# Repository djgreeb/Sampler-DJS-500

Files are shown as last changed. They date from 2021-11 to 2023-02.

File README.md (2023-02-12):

# Sampler DJS-500 nexus

This is a sampler project that has a design in CDJ-2000 nexus and DJM-900 nexus style. The look and feel and the GUI have the same style. 
Sampler based on STM32F746G-DISCO board and pads from Akai LPD8. Replaced RGB LEDs in the pads.
The sampler supports Pro Dj Link. It automatically selects the master deck, can receive information about BPM and beat moments, beats from the CDJ. 
This allows you to synchronize samples with the track on the air, as well as trigger samples without delays using quantize.
Samples are stored on a micro SD card, wav format is supported.

https://youtu.be/_pMT7O0JRTI

https://youtu.be/_ofyAOzehKc

https://youtu.be/i8zc_d4uLBs

https://youtu.be/rUySWEsYK1w

# The current firmware version is 1.77

	ver. 0.35
		- added all periph buttons, leds, VRs and encoder
	ver. 0.36
		- added buttons handler
	ver. 0.37
		- added USB USART debug code
		- added first service mode 
	ver. 0.38
		- improved encoder noise canceller code
	ver. 0.41
		- added service mode code parts
		- added ADCs VRs code with hysteresis and filter
	ver. 0.45
		- added service mode code parts
	ver. 0.46
		- fixed SERVICE MODE code
	ver. 0.47
		- added sync out led blink
	ver. 0.48
		- the signals from the pads are inverted, the pullups are replaced with pulldowns. It is also changed in the hardware
	ver. 0.49
		- added PWM backlight
	ver. 0.51
		- added PRESETS select display
	ver. 0.53
		- added reading preset preview pads color, rating
		- added loading presets from preset list
		- added long blink encoder led if the preset is loaded for a very long time 
	ver. 0.54
		- added color instruments icons
		- added shadow at the rating stars
	ver. 0.57
		- added sync pitch 
		- added imitate deck mode
		- added blink pads
	ver. 0.61
		- added dynamic timeline on waveforms 
		- added colored CUE points and colored samle name
	ver. 0.63
		- added first sequencer
	ver. 0.65
		- minor fixes for the GUI sequencer
		- added status bar with playback status
		- added icons for effect and sync. out
	ver. 0.67
		- added on-off pads label
	ver. 0.68
		- minor fixes GUI
	ver. 0.70
		- fixed pad1 RGB led problem
		- minor fixes
	ver. 0.72
		- minor GUI fixes
		- added UTILITY window
		- added master bpm shield
	ver. 0.73
		- added timestamp for pads press moments and filter 
		- added ATT_LV for pads
	ver. 0.74
		- changed "+" symbol in 15P font
		- minol fixes in gui preset list
		- added gui.h and audio.h
	ver. 0.77
		- added EDIT PRESER window
		- changed SYNC OUT and EFFECT GUI gray color
	ver. 0.79
		- improved debug mode
		- added interrupt for received uart
	ver. 0.80
		- added processing to the EDIT for the encoder button
		- changed project structure main.c file is split into many * .h files
	ver. 0.81
		- added preset list edit menu
	ver. 0.87
		- added DELETE DIALOG
		- added encoder_handler.h, key_handler.h
		- improved  DELETE DIALOG
		- added noise filter for encoder button
	ver. 0.88
		- fixed fixed bugs in GUI UTILITY
		- improved GUI preset list
		- improved the mechanism for creating screenshots, using both layers
	ver. 0.89
		- improved configuration in ffconf.h
	ver. 0.90
		- improved preset list gui
	ver. 0.91
		- improved UTILITY
		- add edit pad display, edit preset display, edit FL display
	ver. 0.94
		- improved UTILITY id address set
	ver. 0.98
		- added utility edit menu
		- added internal bpm generator
	ver. 1.06
		- added write uSD prc
	ver. 1.09
		- added edit preset display
		- added write preset uSD prc 
		- added keyboard and rename prc		
		- added keyboard animation	
	ver. 1.17
		- added blinking cursor for kyeboard
		- added waveform editor
		- improved edit pad display gui
		- improved home display gui
		- added simple waveform analyzer
	ver. 1.19
		- improved edit pad display
		- added prompt for edit pad display
		- added prompt for edit preset display
		- added first BROWSER display
	ver. 1.23
		- replaced FATFS lib! (previous lib not work USE_LFN for READDIR)
	ver. 1.25
		- fixed display of sample names inside folders. Folder removed from title bar
		- fixed edit pad GUI bugs
		- added realtime pad color update when editing a pad
	ver. 1.26
		- fixed ethernetif.c beat process for external sync
		- added FLLIST_DISPLAY
	ver. 1.28
		- added sequence editor
	ver. 1.31
		- minor fixes
		- added [folder] style in BROWSER display
		- added dynamic pad in edit pad display gui
	ver. 1.33
		- added first FL presets animation
	ver. 1.34
		- improved FL presets animation
	ver. 1.35
		- added "create new preset" and "create duplicate" process
	ver. 1.36
		- improved "create new preset" and "create duplicate" process
		- added "preset list is full" and "error x" msg
		- added automaticly wzoom for waveform
	ver. 1.37
		- added noise filters for buttons PRESET, SHIFT, EDIT, BACK, EFFECT
	ver. 1.39
		- added delete prc
		- fixed display of MAC-address in service mode
	ver. 1.40
		- fixed delete prc
	ver. 1.42
		- work on the edit fl list
	ver. 1.43
		- new FL preset load animation
	ver. 1.44
		- added background picture on edit preset display
		- added FIR filter in WFMCREATE()
	ver. 1.47
		- improved WFMCREATE(), FIR and analising algorythm
		- the algorithm for displaying a big waveform has been changed
		- added a mechanism for creating a template Presets.pst file on an empty sd card
	ver. 1.48
		- changed color map for big waveform
	ver. 1.51
		- fixed a bug: where inactive pads in the edit_pad_display would start glowing after the pad_x being edited was stopped
		- improved edit_pad_display
	ver. 1.55
		- bug fixes in the function REDRAW_PAD_EDIT()
		- added first move preset display
	ver. 1.56
		- bug fixes in the MOVE_PRESET	
		- first move_preser_prc
	ver. 1.57
		- improved move_preser_prc	
	ver. 1.59
		- bug fixes in the function REDRAW_PAD_EDIT()
		- added new icons for presets
	ver. 1.60
		- added new icons for presets
	ver. 1.61
		- changed PLL frequency multiplier PeriphClkInitStruct.PLLI2S.PLLI2SN = 271 (135 old)
	ver. 1.65
		- quantize first
	ver. 1.68
		- improved quantize process
		- minor fixes
		- added first effects
	ver. 1.69
		- improved trans effect process
	ver. 1.70
		- optimized and improved trans effect process
	ver. 1.71
		- added ram fill percentage status
	ver. 1.73
		- optimized HAL_SAI_Transmit_IT
		- added uart sync out signal
	ver. 1.74
		- bug fixed in audio handler limiting play_adr size at 0xFFFFF
		- added errors descriptor
		- bug fixed in waveform color draw_st_wvfm()
	ver. 1.75
		- changed the principle of operation of SPI2 for PADS LEDs. Now SPI2 works via DMA.
	ver. 1.77
		- improved performance of Moog Filter and LPF

# Menu navigation
Menu navigation

# Screenshots
SCREEN_009
SCREEN_110
SCREEN_124
SCREEN_176
SCREEN_189
SCREEN_191
SCREEN_195
SCREEN_217 new
SCREEN_217
SCREEN_236
SCREEN_249
SCREEN_285
SCREEN_414
SCREEN_449_new
SCREEN_456
SCREEN_475
SCREEN_734
SCREEN_740
SCREEN_749
SCREEN_757
SCREEN_758
SCREEN_795
SCREEN_839
SCREEN_905_new
SCREEN_956

Some photos:

2020_07_29_23_54_IMG_2746
2020_08_02_23_38_IMG_2779
2020_09_19_19_30_IMG_2952
2020_09_19_19_30_IMG_2953
2020_09_29_15_57_IMG_3006
2020_09_30_11_38_IMG_3007
2020_10_15_12_30_IMG_3105
2020_11_01_00_35_IMG_3214
2020_11_01_02_20_IMG_3215
2020_11_01_15_38_IMG_3219
2020_11_01_21_26_IMG_3228
2020_11_01_21_26_IMG_3229
2020_11_03_14_13_IMG_3241
2020_11_03_21_55_IMG_3242
2020_11_03_23_34_IMG_3244
2020_11_23_22_04_IMG_3343
2020_11_29_21_47_IMG_3356
2020_11_29_21_54_IMG_3357
2020_12_03_11_01_IMG_3373
2020_12_04_14_35_IMG_3376
2020_12_04_21_59_IMG_3377
2020_12_05_16_33_IMG_3378
2020_12_05_17_58_IMG_3380
2020_12_05_17_58_IMG_3381
2020_12_15_12_30_IMG_3422
2020_12_15_12_30_IMG_3423
2020_12_15_12_30_IMG_3424
2020_12_15_12_31_IMG_3425
2020_12_17_21_16_IMG_3439

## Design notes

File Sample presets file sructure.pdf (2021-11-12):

## Sample presets file structure

10.03.2021

## Pad structure [192]:

| 0 | 1 | 2 | 3 | 4 | 5 | 6 | 7 | 8 | 9 | 10 | 11 | 12 | 13 | 14 | 15
0 | ENB | COL | TYPE | Q | S | TRIG | BPM | | G | ST | ST | ST | AL | AL | AL | AL
16 | Sample name. Max 64 symbols.
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
Waveform data [100] or sequencer[64] + number of squares[1]

176 | 0 | 0 | 0 | 0 | 0 | 0 | 0 | 0 | 0 | 0 | 0 | 0

ENB – enable pad. 0 – none, 135 – enable.

COL – color pad. 0 – pink, 1 – red, 2 – orange, 3 – yellow, 4 – green, 5 – aqua, 6 – blue, 7 – purple. 0xFF – none.

TYPE – type pad. 0 – sample, 1 – sequencer.

Q – quantize. 0 – none, 1 – enable.

S – sync only BPM sample to master track.

TRIG – trigger. 0 – one shot, 1 – loop.

BPM – original sample’s BPM. (BPM*10).

G – GAIN in –dB. (-dB*10).

ST – start position in audio frames (3 bytes).

AL - total long track in audio frames (4 bytes). (IS NOT LONG DATA IN FILE. IT IS DATA IN SDRAM)

Waveform data: MSB bit – color, 4 LSB bits – amplitude.

Sequencer: byte==0 – none, byte==1 – start sample. Number of squares byte==0 (1 square). byte==3 (4 square (max)).

## Preset structure [1584]:

Max. 64 presets.

| 0 | 1 | 2 | 3 | 4 | 5 | 6 | 7 | 8 | 9 | 10 | 11 | 12 | 13 | 14 | 15
0 | ENB | ICON | RAT | RCOL | 0 | 0 | 0 | 0 | 0 | 0 | 0 | 0 | 0 | 0 | 0 | 0
16 | Preset name. Max 32 symbols.
32
48
PAD 0[192]

224
240 | PAD 1[192]

416
432

608

PAD 2[192]

624

800

PAD 3[192]

816

992

PAD 4[192]

1008

1184

PAD 5[192]

1200

1376

PAD 6[192]

1392

1568

PAD 7[192]

ENB – enable preset. ENB==117 – preset enable.

ICON – type preset icon

RAT – rating 0…5

RCOL – rating color 0…7 and 0xFF - default

Path: 0:/SAMPLER/ Presets.pst

File name: Presets.pst

## Sample presets file structure[48+TPRS*1584]

| 0 | 1 | 2 | 3 | 4 | 5 | 6 | 7 | 8 | 9 | 10 | 11 | 12 | 13 | 14 | 15
0 | TPRS | 0 | 0 | 0 | 0 | 0 | 0 | 0 | 0 | 0 | 0 | 0 | CPR | BL | BPM
16 | FL0 | FL1 | FL2 | FL3 | FL4 | FL5 | FL6 | FL7 | 0 | 0 | 0 | 0 | 0 | 0 | 0 | 0
32 | 0 | 0 | 0 | 0 | 0 | 0 | 0 | 0 | 0 | 0 | 0 | 0 | 0 | 0 | 0 | 0
48 | PRESET 0[1584]

1632
PRESET 1[1584]]

3216

4784

PRESET 2[1584]

4800
PRESET 3[1584]

6384
PRESET 4[1584]

7968

| PRESET 5[1584]
9552 | PRESET 6[1584]

11136
PRESET 7[1584]

12720
PRESET 8[1584]

14304
PRESET 9[1584]

15888
PRESET 10[1584]

48+
N*1584 | PRESET N[1584]

TPRS – total presets.

FL0- FL7 – fast loading of a preset via a pad. 0xFF – none preset.

BPM – internal bpm for work without synchronization signal.

BL – backlight level.

CPR – current preset number for auto start. 0…63. 0xFF-not auto loading

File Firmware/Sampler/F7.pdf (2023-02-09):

## F7 Project Configuration Report

# 1. Description

## 1.1. Project

Project Name | F7
Board Name | STM32F746G-DISCO
Generated with: | STM32CubeMX 4.22.0
Date | 11/23/2022

## 1.2. MCU

MCU Series | STM32F7
MCU Line | STM32F7x6
MCU name | STM32F746NGHx
MCU Package | TFBGA216
MCU Pin number | 216

# 2. Pinout Configuration

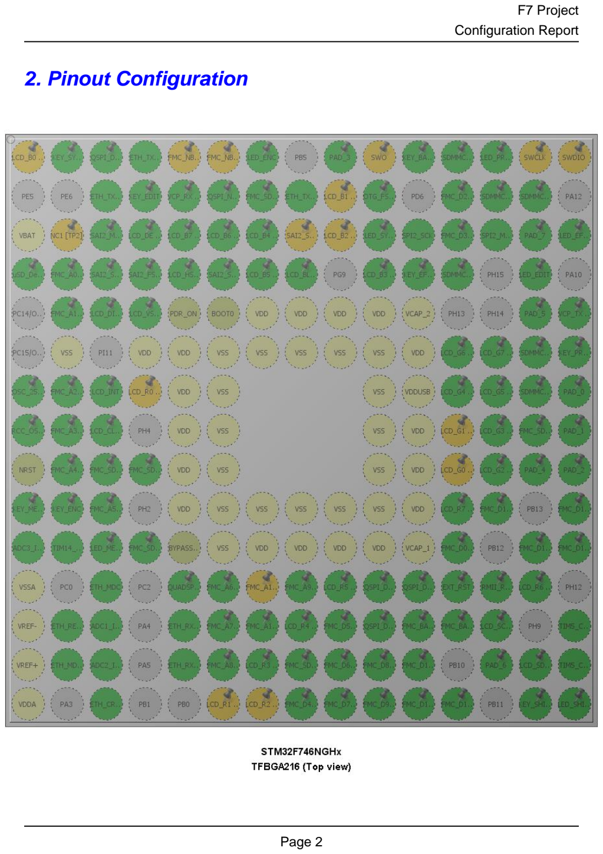
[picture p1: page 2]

# 3. Pins Configuration

Pin Number TFBGA216 | Pin Name (function after reset) | Pin Type | Alternate Function(s) | Label
A1 | PE4 * | I/O | LTDC_B0 | LCD_B0 [RK043FN48H-CT672B_B0]
A2 | PE3 ** | I/O | GPIO_Input | KEY_SYNC_OUT
A3 | PE2 | I/O | QUADSPI_BK1_IO2 | QSPI_D2 [N25Q128A13EF840E_DQ2 ]
A4 | PG14 | I/O | ETH_TXD1
A5 | PE1 * | I/O | FMC_NBL1 | FMC_NBL1 [MT48LC4M32B2B5-6A_DQM1]
A6 | PE0 * | I/O | FMC_NBL0 | FMC_NBL0 [MT48LC4M32B2B5-6A_DQM0]
A7 | PB8 ** | I/O | GPIO_Output | LED_ENC
A9 | PB4 ** | I/O | GPIO_Input | PAD_3
A10 | PB3 * | I/O | SYS_JTDO-SWO | SWO
A11 | PD7 ** | I/O | GPIO_Input | KEY_BACK
A12 | PC12 | I/O | SDMMC1_CK | SDMMC_CK
A13 | PA15 ** | I/O | GPIO_Output | LED_PRESET
A14 | PA14 * | I/O | SYS_JTCK-SWCLK | SWCLK
A15 | PA13 * | I/O | SYS_JTMS-SWDIO | SWDIO
B3 | PG13 | I/O | ETH_TXD0
B4 | PB9 ** | I/O | GPIO_Input | KEY_EDIT
B5 | PB7 | I/O | USART1_RX | VCP_RX [STM32F103CBT6_PA2]
B6 | PB6 | I/O | QUADSPI_BK1_NCS | QSPI_NCS [N25Q128A13EF840E_S]
B7 | PG15 | I/O | FMC_SDNCAS | FMC_SDNCAS [MT48LC4M32B2B5-6A_CAS]
B8 | PG11 | I/O | ETH_TX_EN
B9 | PJ13 * | I/O | LTDC_B1 | LCD_B1 [RK043FN48H-CT672B_B1]
B10 | PJ12 ** | I/O | GPIO_Input | OTG_FS_VBUS
B12 | PD0 | I/O | FMC_D2 | FMC_D2 [MT48LC4M32B2B5-6A_DQ2]
B13 | PC11 | I/O | SDMMC1_D3 | SDMMC_D3

Pin Number TFBGA216 | Pin Name (function after reset) | Pin Type | Alternate Function(s) | Label
B14 | PC10 | I/O | SDMMC1_D2 | SDMMC_D2
C1 | VBAT | Power
C2 | PI8 * | I/O | RTC_TS | NC1 [TP2]
C3 | PI4 | I/O | SAI2_MCLK_A | SAI2_MCLKA [WM8994ECS/R_MCLK1]
C4 | PK7 | I/O | LTDC_DE | LCD_DE [RK043FN48H-CT672B_DE]
C5 | PK6 | I/O | LTDC_B7 | LCD_B7 [RK043FN48H-CT672B_B7]
C6 | PK5 | I/O | LTDC_B6 | LCD_B6 [RK043FN48H-CT672B_B6]
C7 | PG12 | I/O | LTDC_B4 | LCD_B4 [RK043FN48H-CT672B_B4]
C8 | PG10 * | I/O | SAI2_SD_B | SAI2_SDB [WM8994ECS/R_ADCDAT1 ]
C9 | PJ14 * | I/O | LTDC_B2 | LCD_B2 [RK043FN48H-CT672B_B2]
C10 | PD5 ** | I/O | GPIO_Output | LED_SYNC_OUT
C11 | PD3 | I/O | SPI2_SCK
C12 | PD1 | I/O | FMC_D3 | FMC_D3 [MT48LC4M32B2B5-6A_DQ3]
C13 | PI3 | I/O | SPI2_MOSI
C14 | PI2 ** | I/O | GPIO_Input | PAD_7
C15 | PA11 ** | I/O | GPIO_Output | LED_EFFECT
D1 | PC13 ** | I/O | GPIO_Input | uSD_Detect
D2 | PF0 | I/O | FMC_A0 | FMC_A0 [MT48LC4M32B2B5-6A_A0]
D3 | PI5 | I/O | SAI2_SCK_A | SAI2_SCKA [WM8994ECS/R_BCLK1]
D4 | PI7 | I/O | SAI2_FS_A | SAI2_FSA [WM8994ECS/R_LRCLK1]
D5 | PI10 | I/O | LTDC_HSYNC | LCD_HSYNC [RK043FN48H-CT672B_HSYNC]
D6 | PI6 | I/O | SAI2_SD_A | SAI2_SDA [WM8994ECS/R_DACDAT1 ]
D7 | PK4 | I/O | LTDC_B5 | LCD_B5 [RK043FN48H-CT672B_B5]
D8 | PK3 ** | I/O | GPIO_Output | LCD_BL_CTRL [STLD40DPUR_EN]

Pin Number TFBGA216 | Pin Name (function after reset) | Pin Type | Alternate Function(s) | Label
D10 | PJ15 | I/O | LTDC_B3 | LCD_B3 [RK043FN48H-CT672B_B3]
D11 | PD4 ** | I/O | GPIO_Input | KEY_EFFECT
D12 | PD2 | I/O | SDMMC1_CMD | SDMMC_D0
D14 | PI1 ** | I/O | GPIO_Output | LED_EDIT
E2 | PF1 | I/O | FMC_A1 | FMC_A1 [MT48LC4M32B2B5-6A_A1]
E3 | PI12 ** | I/O | GPIO_Output | LCD_DISP [RK043FN48H-CT672B_DISP]
E4 | PI9 | I/O | LTDC_VSYNC | LCD_VSYNC [RK043FN48H-CT672B_VSYNC]
E5 | PDR_ON | Reset
E6 | BOOT0 | Boot
E7 | VDD | Power
E8 | VDD | Power
E9 | VDD | Power
E10 | VDD | Power
E11 | VCAP_2 | Power
E14 | PI0 ** | I/O | GPIO_Input | PAD_5
E15 | PA9 | I/O | USART1_TX | VCP_TX [STM32F103CBT6_PA3]
F2 | VSS | Power
F4 | VDD | Power
F5 | VDD | Power
F6 | VSS | Power
F7 | VSS | Power
F8 | VSS | Power
F9 | VSS | Power
F10 | VSS | Power
F11 | VDD | Power
F12 | PK1 | I/O | LTDC_G6 | LCD_G6 [RK043FN48H-CT672B_G6]
F13 | PK2 | I/O | LTDC_G7 | LCD_G7 [RK043FN48H-CT672B_G7]
F14 | PC9 | I/O | SDMMC1_D1
F15 | PA8 ** | I/O | GPIO_Input | KEY_PRESET
G1 | PH0/OSC_IN | I/O | RCC_OSC_IN | OSC_25M [NZ2520SB-25.00M_OUT]
G2 | PF2 | I/O | FMC_A2 | FMC_A2 [MT48LC4M32B2B5-6A_A2]

Pin Number TFBGA216 | Pin Name (function after reset) | Pin Type | Alternate Function(s) | Label
G3 | PI13 | I/O | GPIO_EXTI13 | LCD_INT
G4 | PI15 * | I/O | LTDC_R0 | LCD_R0 [RK043FN48H-CT672B_R0]
G5 | VDD | Power
G6 | VSS | Power
G10 | VSS | Power
G11 | VDDUSB | Power
G12 | PJ11 | I/O | LTDC_G4 | LCD_G4 [RK043FN48H-CT672B_G4]
G13 | PK0 | I/O | LTDC_G5 | LCD_G5 [RK043FN48H-CT672B_G5]
G14 | PC8 | I/O | SDMMC1_D0
G15 | PC7 ** | I/O | GPIO_Input | PAD_0
H1 | PH1/OSC_OUT | I/O | RCC_OSC_OUT
H2 | PF3 | I/O | FMC_A3 | FMC_A3 [MT48LC4M32B2B5-6A_A3]
H3 | PI14 | I/O | LTDC_CLK | LCD_CLK [RK043FN48H-CT672B_CLK]
H5 | VDD | Power
H6 | VSS | Power
H10 | VSS | Power
H11 | VDD | Power
H12 | PJ8 * | I/O | LTDC_G1 | LCD_G1 [RK043FN48H-CT672B_G1]
H13 | PJ10 | I/O | LTDC_G3 | LCD_G3 [RK043FN48H-CT672B_G3]
H14 | PG8 | I/O | FMC_SDCLK | FMC_SDCLK [MT48LC4M32B2B5-6A_CLK]
H15 | PC6 ** | I/O | GPIO_Input | PAD_1
J1 | NRST | Reset
J2 | PF4 | I/O | FMC_A4 | FMC_A4 [MT48LC4M32B2B5-6A_A4]
J3 | PH5 | I/O | FMC_SDNWE | FMC_SDNME [MT48LC4M32B2B5-6A_WE]
J4 | PH3 | I/O | FMC_SDNE0 | FMC_SDNE0 [MT48LC4M32B2B5-6A_CS]
J5 | VDD | Power
J6 | VSS | Power
J10 | VSS | Power

Pin Number TFBGA216 | Pin Name (function after reset) | Pin Type | Alternate Function(s) | Label
J11 | VDD | Power
J12 | PJ7 * | I/O | LTDC_G0 | LCD_G0 [RK043FN48H-CT672B_G0]
J13 | PJ9 | I/O | LTDC_G2 | LCD_G2 [RK043FN48H-CT672B_G2]
J14 | PG7 ** | I/O | GPIO_Input | PAD_4
J15 | PG6 ** | I/O | GPIO_Input | PAD_2
K1 | PF7 ** | I/O | GPIO_Input | KEY_MENU
K2 | PF6 ** | I/O | GPIO_Input | KEY_ENC
K3 | PF5 | I/O | FMC_A5 | FMC_A5 [MT48LC4M32B2B5-6A_A5]
K5 | VDD | Power
K6 | VSS | Power
K7 | VSS | Power
K8 | VSS | Power
K9 | VSS | Power
K10 | VSS | Power
K11 | VDD | Power
K12 | PJ6 | I/O | LTDC_R7 | LCD_R7 [RK043FN48H-CT672B_R7]
K13 | PD15 | I/O | FMC_D1 | FMC_D1 [MT48LC4M32B2B5-6A_DQ1]
K15 | PD10 | I/O | FMC_D15 | FMC_D15 [MT48LC4M32B2B5-6A_DQ15]
L1 | PF10 | I/O | ADC3_IN8
L2 | PF9 | I/O | TIM14_CH1
L3 | PF8 ** | I/O | GPIO_Output | LED_MENU
L4 | PC3 | I/O | FMC_SDCKE0 | FMC_SDCKE0 [MT48LC4M32B2B5-6A_CKE]
L5 | BYPASS_REG | Reset
L6 | VSS | Power
L7 | VDD | Power
L8 | VDD | Power
L9 | VDD | Power
L10 | VDD | Power
L11 | VCAP_1 | Power
L12 | PD14 | I/O | FMC_D0 | FMC_D0 [MT48LC4M32B2B5-6A_DQ0]

Pin Number TFBGA216 | Pin Name (function after reset) | Pin Type | Alternate Function(s) | Label
L14 | PD9 | I/O | FMC_D14 | FMC_D14 [MT48LC4M32B2B5-6A_DQ14]
L15 | PD8 | I/O | FMC_D13 | FMC_D13 [MT48LC4M32B2B5-6A_DQ13]
M1 | VSSA | Power
M3 | PC1 | I/O | ETH_MDC
M5 | PB2 | I/O | QUADSPI_CLK
M6 | PF12 | I/O | FMC_A6 | FMC_A6 [MT48LC4M32B2B5-6A_A6]
M7 | PG1 * | I/O | FMC_A11 | FMC_A11 [MT48LC4M32B2B5-6A_A11]
M8 | PF15 | I/O | FMC_A9 | FMC_A9 [MT48LC4M32B2B5-6A_A9]
M9 | PJ4 | I/O | LTDC_R5 | LCD_R5 [RK043FN48H-CT672B_R5]
M10 | PD12 | I/O | QUADSPI_BK1_IO1 | QSPI_D1 [N25Q128A13EF840E_DQ1 ]
M11 | PD13 | I/O | QUADSPI_BK1_IO3 | QSPI_D3 [N25Q128A13EF840E_DQ3 ]
M12 | PG3 ** | I/O | GPIO_Output | EXT_RST
M13 | PG2 ** | I/O | GPIO_Input | RMII_RXER
M14 | PJ5 | I/O | LTDC_R6 | LCD_R6 [RK043FN48H-CT672B_R6]
N1 | VREF- | Power
N2 | PA1 | I/O | ETH_REF_CLK
N3 | PA0/WKUP | I/O | ADC1_IN0
N5 | PC4 | I/O | ETH_RXD0
N6 | PF13 | I/O | FMC_A7 | FMC_A7 [MT48LC4M32B2B5-6A_A7]
N7 | PG0 | I/O | FMC_A10 | FMC_A10 [MT48LC4M32B2B5-6A_A10]
N8 | PJ3 | I/O | LTDC_R4 | LCD_R4 [RK043FN48H-CT672B_R4]
N9 | PE8 | I/O | FMC_D5 | FMC_D5 [MT48LC4M32B2B5-6A_DQ5]

Pin Number TFBGA216 | Pin Name (function after reset) | Pin Type | Alternate Function(s) | Label
N10 | PD11 | I/O | QUADSPI_BK1_IO0 | QSPI_D0 [N25Q128A13EF840E_DQ0 ]
N11 | PG5 | I/O | FMC_BA1 | FMC_BA1 [MT48LC4M32B2B5-6A_BA1]
N12 | PG4 | I/O | FMC_BA0 | FMC_BA0 [MT48LC4M32B2B5-6A_BA0]
N13 | PH7 | I/O | I2C3_SCL | LCD_SCL [RK043FN48H-CT672B_SCL]
N15 | PH11 | I/O | TIM5_CH2
P1 | VREF+ | Power
P2 | PA2 | I/O | ETH_MDIO
P3 | PA6 | I/O | ADC2_IN6
P5 | PC5 | I/O | ETH_RXD1
P6 | PF14 | I/O | FMC_A8 | FMC_A8 [MT48LC4M32B2B5-6A_A8]
P7 | PJ2 | I/O | LTDC_R3 | LCD_R3 [RK043FN48H-CT672B_R3]
P8 | PF11 | I/O | FMC_SDNRAS | FMC_SDNRAS [MT48LC4M32B2B5-6A_RAS]
P9 | PE9 | I/O | FMC_D6 | FMC_D6 [MT48LC4M32B2B5-6A_DQ6]
P10 | PE11 | I/O | FMC_D8 | FMC_D8 [MT48LC4M32B2B5-6A_DQ8]
P11 | PE14 | I/O | FMC_D11 | FMC_D11 [MT48LC4M32B2B5-6A_DQ11]
P13 | PH6 ** | I/O | GPIO_Input | PAD_6
P14 | PH8 | I/O | I2C3_SDA | LCD_SDA [RK043FN48H-CT672B_SDA]
P15 | PH10 | I/O | TIM5_CH1
R1 | VDDA | Power
R3 | PA7 | I/O | ETH_CRS_DV
R6 | PJ0 * | I/O | LTDC_R1 | LCD_R1 [RK043FN48H-CT672B_R1]
R7 | PJ1 * | I/O | LTDC_R2 | LCD_R2 [RK043FN48H-CT672B_R2]

Pin Number TFBGA216 | Pin Name (function after reset) | Pin Type | Alternate Function(s) | Label
R8 | PE7 | I/O | FMC_D4 | FMC_D4 [MT48LC4M32B2B5-6A_DQ4]
R9 | PE10 | I/O | FMC_D7 | FMC_D7 [MT48LC4M32B2B5-6A_DQ7]
R10 | PE12 | I/O | FMC_D9 | FMC_D9 [MT48LC4M32B2B5-6A_DQ9]
R11 | PE15 | I/O | FMC_D12 | FMC_D12 [MT48LC4M32B2B5-6A_DQ12]
R12 | PE13 | I/O | FMC_D10 | FMC_D10 [MT48LC4M32B2B5-6A_DQ10]
R14 | PB14 ** | I/O | GPIO_Input | KEY_SHIFT
R15 | PB15 ** | I/O | GPIO_Output | LED_SHIFT

## ** The pin is affected with an I/O function * The pin is affected with a peripheral function but no peripheral mode is activated

# 4. Clock Tree Configuration

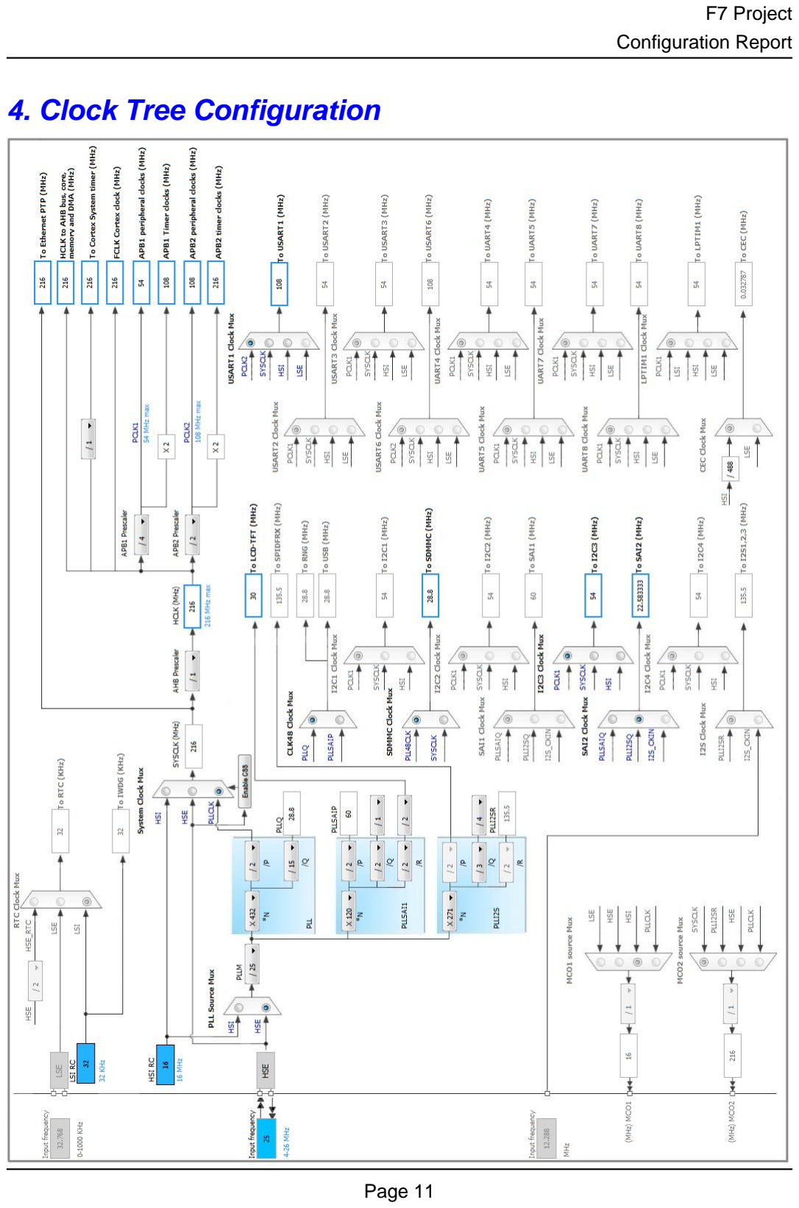
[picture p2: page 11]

# 5. IPs and Middleware Configuration

# 5.1. ADC1

## mode: IN0

## 5.1.1. Parameter Settings:

### ADCs_Common_Settings:

Mode | Independent mode

### ADC_Settings:

Clock Prescaler | PCLK2 divided by 4
Resolution | 12 bits (15 ADC Clock cycles)
Data Alignment | Right alignment
Scan Conversion Mode | Disabled
Continuous Conversion Mode | Disabled
Discontinuous Conversion Mode | Disabled
DMA Continuous Requests | Disabled
End Of Conversion Selection | EOC flag at the end of single channel conversion

### ADC_Regular_ConversionMode:

Number Of Conversion | 1
External Trigger Conversion Source | Regular Conversion launched by software
External Trigger Conversion Edge | None
Rank | 1
Channel | Channel 0
Sampling Time | 3 Cycles

### ADC_Injected_ConversionMode:

Number Of Conversions | 0

### WatchDog:

Enable Analog WatchDog Mode | false

# 5.2. ADC2

## mode: IN6

## 5.2.1. Parameter Settings:

### ADCs_Common_Settings:

Mode | Independent mode

### ADC_Settings:

Clock Prescaler | PCLK2 divided by 4
Resolution | 12 bits (15 ADC Clock cycles)
Data Alignment | Right alignment
Scan Conversion Mode | Disabled
Continuous Conversion Mode | Disabled
Discontinuous Conversion Mode | Disabled
DMA Continuous Requests | Disabled
End Of Conversion Selection | EOC flag at the end of single channel conversion

### ADC_Regular_ConversionMode:

Number Of Conversion | 1
External Trigger Conversion Source | Regular Conversion launched by software
External Trigger Conversion Edge | None
Rank | 1
Channel | Channel 6
Sampling Time | 3 Cycles

### ADC_Injected_ConversionMode:

Number Of Conversions | 0

### WatchDog:

Enable Analog WatchDog Mode | false

# 5.3. ADC3

## mode: IN8

## 5.3.1. Parameter Settings:

### ADCs_Common_Settings:

Mode | Independent mode

### ADC_Settings:

Clock Prescaler | PCLK2 divided by 4
Resolution | 12 bits (15 ADC Clock cycles)
Data Alignment | Right alignment
Scan Conversion Mode | Disabled
Continuous Conversion Mode | Disabled
Discontinuous Conversion Mode | Disabled
DMA Continuous Requests | Disabled
End Of Conversion Selection | EOC flag at the end of single channel conversion

### ADC_Regular_ConversionMode:

Number Of Conversion | 1
External Trigger Conversion Source | Regular Conversion launched by software
External Trigger Conversion Edge | None
Rank | 1
Channel | Channel 8
Sampling Time | 3 Cycles

### ADC_Injected_ConversionMode:

Number Of Conversions | 0

### WatchDog:

Enable Analog WatchDog Mode | false

# 5.4. DMA2D

## mode: Activated

## 5.4.1. Parameter Settings:

### Basic Parameters:

Transfer Mode | Memory to Memory
Color Mode | ARGB8888
Output Offset | 0

### Foreground layer Configuration:

DMA2D Input Color Mode | ARGB8888
DMA2D ALPHA MODE | No modification of the alpha channel value
Input Alpha | 0
Input Offset | 0
DMA2D ALPHA Inversion | Regular Alpha
DMA2D Red and Blue swap | Regular mode (RGB or ARGB)

# 5.5. ETH

## Mode: RMII

## 5.5.1. Parameter Settings:

### Advanced : Ethernet Media Configuration:

Auto Negotiation | Enabled

### General : Ethernet Configuration:

Ethernet MAC Address

| EE:81:EA:AA:DD:F1 *
PHY Address | 0 *

### Ethernet Basic Configuration:

Rx Mode | Polling Mode
TX IP Header Checksum Computation | By hardware

## 5.5.2. Advanced Parameters:

### External PHY Configuration:

PHY | LAN8742A_PHY_ADDRESS
PHY Address Value | 0
PHY Reset delay these values are based on a 1 ms Systick interrupt | 0x000000FF *
PHY Configuration delay | 0x00000FFF *
PHY Read TimeOut | 0x0000FFFF *
PHY Write TimeOut | 0x0000FFFF *

### Common : External PHY Configuration:

Transceiver Basic Control Register | 0x00 *
Transceiver Basic Status Register | 0x01 *
PHY Reset | 0x8000 *
Select loop-back mode | 0x4000 *
Set the full-duplex mode at 100 Mb/s | 0x2100 *
Set the half-duplex mode at 100 Mb/s | 0x2000 *
Set the full-duplex mode at 10 Mb/s | 0x0100 *
Set the half-duplex mode at 10 Mb/s | 0x0000 *
Enable auto-negotiation function | 0x1000 *
Restart auto-negotiation function | 0x0200 *
Select the power down mode | 0x0800 *
Isolate PHY from MII | 0x0400 *
Auto-Negotiation process completed | 0x0020 *
Valid link established | 0x0004 *
Jabber condition detected | 0x0002 *

### Extended : External PHY Configuration:

PHY special control/status register Offset | 0x10 *
PHY Speed mask | 0x0002 *
PHY Duplex mask | 0x0004 *
PHY Interrupt Source Flag register Offset | 0x000B *

PHY Link down inturrupt | 0x000B *

# 5.6. FMC

## SDRAM 1

## Clock and chip enable: SDCKE0+SDNE0 Internal bank number: 4 banks Address: 11 bits Data: 16 bits

## 5.6.1. SDRAM 1:

### SDRAM control:

Bank | SDRAM bank 1
Number of column address bits | 8 bits
Number of row address bits | 11 bits
CAS latency | 2 memory clock cycles *
Write protection | Disabled
SDRAM common clock | Disabled
SDRAM common burst read | Enabled *
SDRAM common read pipe delay | 0 HCLK clock cycle

### SDRAM timing in memory clock cycles:

Load mode register to active delay | 2 *
Exit self-refresh delay | 6 *
Self-refresh time | 4 *
SDRAM common row cycle delay | 6 *
Write recovery time | 2 *
SDRAM common row precharge delay | 2 *
Row to column delay | 2 *

# 5.7. I2C3

## I2C: I2C

## 5.7.1. Parameter Settings:

### Timing configuration:

I2C Speed Mode | Standard Mode
I2C Speed Frequency (KHz) | 100
Rise Time (ns) | 0
Fall Time (ns) | 0
Coefficient of Digital Filter | 0
Analog Filter | Enabled
Timing | 0x20404768 *

### Slave Features:

Clock No Stretch Mode | Disabled
General Call Address Detection | Disabled
Primary Address Length selection | 7-bit
Dual Address Acknowledged | Disabled
Primary slave address | 0

# 5.8. LTDC

## Display Type: RGB565 (16 bits)

## 5.8.1. Parameter Settings:

### Synchronization for Width:

Horizontal Synchronization Width | 41 *
Horizontal Back Porch | 13 *
Active Width | 480 *
Horizontal Front Porch | 32 *
HSync Width | 40
Accumulated Horizontal Back Porch Width | 53
Accumulated Active Width | 533
Total Width | 565

### Synchronization for Height:

Vertical Synchronization Height | 10 *
Vertical Back Porch | 2
Active Height | 272 *
Vertical Front Porch | 2
VSync Height | 9
Accumulated Vertical Back Porch Height | 11
Accumulated Active Height | 283

Total Height | 285

### Signal Polarity:

Horizontal Synchronization Polarity | Active Low
Vertical Synchronization Polarity | Active Low
Data Enable Polarity | Active Low
Pixel Clock Polarity | Normal Input

### BackGround Color:

Red | 0
Green | 0
Blue | 0

## 5.8.2. Layer Settings:

### BackGround Color:

Layer 0 - Blue | 0
Layer 0 - Green | 0
Layer 0 - Red | 0
Layer 1 - Blue | 0
Layer 1 - Green | 0
Layer 1 - Red | 0

### Windows Position:

Layer 0 - Window Horizontal Start | 0
Layer 0 - Window Horizontal Stop | 480 *
Layer 0 - Window Vertical Start | 0
Layer 0 - Window Vertical Stop | 272 *
Layer 1 - Window Horizontal Start | 0
Layer 1 - Window Horizontal Stop | 480 *
Layer 1 - Window Vertical Start | 0
Layer 1 - Window Vertical Stop | 272 *

### Pixel Parameters:

Layer 0 - Pixel Format | ARGB8888
Layer 1 - Pixel Format | ARGB8888

### Blending:

Layer 0 - Alpha constant for blending | 255 *
Layer 0 - Default Alpha value | 0
Layer 0 - Blending Factor1 | Alpha constant
Layer 0 - Blending Factor2 | Alpha constant
Layer 1 - Alpha constant for blending | 255 *
Layer 1 - Default Alpha value | 0
Layer 1 - Blending Factor1 | Alpha constant

Layer 1 - Blending Factor2 | Alpha constant

### Frame Buffer:

Layer 0 - Color Frame Buffer Start Adress | 0
Layer 0 - Color Frame Buffer Line Length (Image Width) | 0
Layer 0 - Color Frame Buffer Number of Lines (Image Height) | 0
Layer 1 - Color Frame Buffer Start Adress | 0
Layer 1 - Color Frame Buffer Line Length (Image Width) | 0
Layer 1 - Color Frame Buffer Number of Lines (Image Height) | 0

### Number of Layers:

Number of Layers | 2 layers

# 5.9. QUADSPI

## QuadSPI Mode: Bank1 with Quad SPI Lines

## 5.9.1. Parameter Settings:

### General Parameters:

Clock Prescaler | 1 *
Fifo Threshold | 4 *
Sample Shifting | Sample Shifting Half Cycle *
Flash Size | 23 *
Chip Select High Time | 2 Cycles *
Clock Mode | Low
Flash ID | Flash ID 1
Dual Flash | Disabled

# 5.10. RCC

## High Speed Clock (HSE): Crystal/Ceramic Resonator

## 5.10.1. Parameter Settings:

### System Parameters:

VDD voltage (V) | 3.3

Flash Latency(WS) | 7 WS (8 CPU cycle)

### RCC Parameters:

HSI Calibration Value | 16
TIM Prescaler Selection | Disabled
HSE Startup Timout Value (ms) | 100
LSE Startup Timout Value (ms) | 5000

### Power Parameters:

Power Over Drive | Enabled
Power Regulatror Voltage Scale | Power Regulator Voltage Scale 1

# 5.11. SAI2

## Mode: Master with Master Clock Out

## 5.11.1. Parameter Settings:

### SAI A:

Basic Parameters
Protocol | Free
Audio Mode | Master Transmit
Frame Length | 64 bits *
Data Size | 16 Bits *
Slot Size | DataSize
Output Mode | Stereo
Companding Mode | No companding mode
SAI SD Line Output Mode | Driven
Frame Parameters
First Bit | MSB First
Frame Synchro Active Level Length | 32 *
Frame Synchro Definition | Channel Identification *
Frame Synchro Polarity | Active Low
Frame Synchro Offset | Before First Bit *

Slot Parameters
First Bit Offset | 0
Number of Slots (only Even Values) | 2
Slot Active Final Value | 0x00000003 *
Slot Active | User Setting *
Slot 0 Active | true *
Slot 1 Active | true *

Clock Parameters
Master Clock Divider | Enabled
Audio Frequency | 44.1 KHz *
Real Audio Frequency | 44.108 KHz *
Error between Selected | -8.1 % *
Clock Strobing | Rising Edge *

Advanced Parameters
Fifo Threshold | Empty
Output Drive | Enabled *
Synchronization External | Disabled

# 5.12. SDMMC1

## Mode: SD 4 bits Wide bus

## 5.12.1. Parameter Settings:

### SDMMC parameters:

SDMMCCLK clock divide factor | 12 *

# 5.13. SPI2

## Mode: Transmit Only Master

## 5.13.1. Parameter Settings:

### Basic Parameters:

Frame Format | Motorola
Data Size | 8 Bits *
First Bit | MSB First

### Clock Parameters:

Prescaler (for Baud Rate) | 16 *
Baud Rate | 3.375 MBits/s *
Clock Polarity (CPOL) | Low
Clock Phase (CPHA) | 1 Edge

### Advanced Parameters:

CRC Calculation | Disabled

NSSP Mode | Disabled *
NSS Signal Type | Software

# 5.14. SYS

## Timebase Source: SysTick

# 5.15. TIM2

## Clock Source : Internal Clock

## 5.15.1. Parameter Settings:

### Counter Settings:

Prescaler (PSC - 16 bits value) | 21599 *
Counter Mode | Up
Counter Period (AutoReload Register - 32 bits value ) | 4 *
Internal Clock Division (CKD) | Division by 2 *
auto-reload preload | Disable

### Trigger Output (TRGO) Parameters:

Master/Slave Mode | Disable (no sync between this TIM (Master) and its Slaves
Trigger Event Selection TRGO | Update Event *

# 5.16. TIM5

## Combined Channels: Encoder Mode

## 5.16.1. Parameter Settings:

### Counter Settings:

Prescaler (PSC - 16 bits value) | 0
Counter Mode | Up
Counter Period (AutoReload Register - 32 bits value ) | 1 *
Internal Clock Division (CKD) | No Division
auto-reload preload | Disable

### Trigger Output (TRGO) Parameters:

Master/Slave Mode | Disable (no sync between this TIM (Master) and its Slaves
Trigger Event Selection TRGO | Reset (UG bit from TIMx_EGR)

### Encoder:

Encoder Mode | Encoder Mode TI1
____ Parameters for Channel 1 ____
Polarity | Rising Edge
IC Selection | Direct
Prescaler Division Ratio | No division
Input Filter | 4 *

____ Parameters for Channel 2 ____
Polarity | Rising Edge
IC Selection | Direct
Prescaler Division Ratio | No division
Input Filter | 4 *

# 5.17. TIM14

## mode: Activated Channel1: PWM Generation CH1

## 5.17.1. Parameter Settings:

### Counter Settings:

Prescaler (PSC - 16 bits value) | 24 *
Counter Mode | Up
Counter Period (AutoReload Register - 16 bits value ) | 255 *
Internal Clock Division (CKD) | Division by 4 *
auto-reload preload | Disable

### PWM Generation Channel 1:

Mode | PWM mode 1
Pulse (16 bits value) | 200 *
Fast Mode | Disable
CH Polarity | High

# 5.18. USART1

## Mode: Asynchronous

## 5.18.1. Parameter Settings:

### Basic Parameters:

Baud Rate | 115200
Word Length | 8 Bits (including Parity) *
Parity | None
Stop Bits | 1

### Advanced Parameters:

Data Direction | Receive and Transmit
Over Sampling | 16 Samples
Single Sample | Disable

### Advanced Features:

Auto Baudrate | Disable
TX Pin Active Level Inversion | Disable
RX Pin Active Level Inversion | Disable
Data Inversion | Disable
TX and RX Pins Swapping | Disable
Overrun | Enable
DMA on RX Error | Enable
MSB First | Disable

# 5.19. FATFS

## mode: SD Card

## 5.19.1. Set Defines:

### Version:

FATFS version | R0.11

### Function Parameters:

FS_READONLY (Read-only mode) | Disabled
FS_MINIMIZE (Minimization level) | Disabled
USE_STRFUNC (String functions) | Enabled with LF -> CRLF conversion
USE_FIND (Find functions) | Disabled
USE_MKFS (Make filesystem function) | Enabled
USE_FASTSEEK (Fast seek function) | Enabled
USE_LABEL (Volume label functions) | Disabled
USE_FORWARD (Forward function) | Disabled

### Locale and Namespace Parameters:

CODE_PAGE (Code page on target) | Multilingual Latin 1 (OEM)
USE_LFN (Use Long Filename) | Enabled with static working buffer on the BSS *

MAX_LFN (Max Long Filename) | 255
LFN_UNICODE (Enable Unicode) | ANSI/OEM
STRF_ENCODE (Character encoding) | UTF-8
FS_RPATH (Relative Path) | Disabled

### Physical Drive Parameters:

VOLUMES (Logical drives) | 1
MAX_SS (Maximum Sector Size) | 4096 *
MIN_SS (Minimum Sector Size) | 512
MULTI_PARTITION (Volume partitions feature) | Disabled
USE_TRIM (Erase feature) | Disabled
FS_NOFSINFO (Force full FAT scan) | 0

### System Parameters:

FS_TINY (Tiny mode) | Disabled
FS_NORTC (Timestamp feature) | Dynamic timestamp
NORTC_YEAR (Year for timestamp) | 2015
NORTC_MON (Month for timestamp) | 6
NORTC_MDAY (Day for timestamp) | 4
WORD_ACCESS (Platform dependent access option) | Byte access
FS_REENTRANT (Re-Entrancy) | Disabled
FS_TIMEOUT (Timeout ticks) | 1000
SYNC_t (O/S sync object) | osSemaphoreId
FS_LOCK (Number of files opened simultaneously) | 2

## 5.19.2. IPs instances:

### SDIO/SDMMC:

SDMMC instance | SDMMC1

# 5.20. LWIP

## mode: Enabled

Advanced parameters are not listed except if modified by user.

## 5.20.1. General Settings:

### LwIP Version:

LwIP Version (Version of LwIP supported by CubeMX ** CubeMX specific **) | 2.0.0

### IPv4 - DHCP Option:

LWIP_DHCP (DHCP Module) | Disabled *

### IP Address Settings:

IP_ADDRESS (IP Address) | 169.254.040.241 *
NETMASK_ADDRESS (Netmask Address) | 255.255.000.000 *
GATEWAY_ADDRESS (Gateway Address) | 169.254.001.001 *

### RTOS Settings:

WITH_RTOS (Use FREERTOS ** CubeMX specific **) | Disabled

### Protocols Options:

LWIP_ICMP (ICMP Module Activation) | Enabled
LWIP_IGMP (IGMP Module) | Disabled
LWIP_DNS (DNS Module) | Disabled
LWIP_UDP (UDP Module) | Enabled
MEMP_NUM_UDP_PCB (Number of UDP Connections) | 5 *
LWIP_TCP (TCP Module) | Enabled
MEMP_NUM_TCP_PCB (Number of TCP Connections) | 5

## 5.20.2. Key Options:

### Infrastructure - OS Awarness Option:

NO_SYS (OS Awarness) | OS Not Used

### Infrastructure - Timers Options:

LWIP_TIMERS (Use Support For sys_timeout) | Enabled

### Infrastructure - Core Locking and MPU Options:

SYS_LIGHTWEIGHT_PROT (Memory Functions Protection) | Disabled

### Infrastructure - Heap and Memory Pools Options:

MEM_SIZE (Heap Memory Size) | 1600

### Infrastructure - Internal Memory Pool Sizes:

MEMP_NUM_PBUF (Number of Memory Pool struct Pbufs) | 16
MEMP_NUM_RAW_PCB (Number of Raw Protocol Control Blocks) | 4
MEMP_NUM_TCP_PCB_LISTEN (Number of Listening TCP Connections) | 8
MEMP_NUM_TCP_SEG (Number of TCP Segments simultaneously queued) | 16
MEMP_NUM_LOCALHOSTLIST (Number of Host Entries in the Local Host List) | 1

### Pbuf Options:

PBUF_POOL_SIZE (Number of Buffers in the Pbuf Pool) | 16
PBUF_POOL_BUFSIZE (Size of each pbuf in the pbuf pool) | 592

### IPv4 - ARP Options:

LWIP_ARP (ARP Functionality) | Enabled

### Callback - TCP Options:

TCP_TTL (Number of Time-To-Live Used by TCP Packets) | 255
TCP_WND (TCP Receive Window Maximum Size) | 2144

TCP_QUEUE_OOSEQ (Allow Out-Of-Order Incoming Packets) | Enabled
TCP_MSS (Maximum Segment Size) | 536
TCP_SND_BUF (TCP Sender Buffer Space) | 1072
TCP_SND_QUEUELEN (Number of Packet Buffers Allowed for TCP Sender) | 9

### Network Interfaces Options:

LWIP_NETIF_STATUS_CALLBACK (Callback Function on Interface Status Changes) | Disabled
LWIP_NETIF_LINK_CALLBACK (Callback Function on Interface Link Changes) | Disabled

### NETIF - Loopback Interface Options:

LWIP_NETIF_LOOPBACK (NETIF Loopback) | Disabled

### Thread Safe APIs - Socket Options:

LWIP_SOCKET (Socket API) | Disabled

## 5.20.3. PPP:

### PPP Options:

PPP_SUPPORT (PPP Module) | Disabled

## 5.20.4. IPv6:

### IPv6 Options:

LWIP_IPV6 (IPv6 Protocol) | Disabled

## 5.20.5. HTTPD:

### HTTPD Options:

LWIP_HTTPD (LwIP HTTPD Support ** CubeMX specific **) | Disabled

## 5.20.6. SNMP:

### SNMP Options:

LWIP_SNMP (LwIP SNMP Agent) | Disabled

## 5.20.7. SNTP:

### SNTP Options:

LWIP_SNTP (LWIP SNTP Support ** CubeMX specific **) | Disabled

## 5.20.8. MDNS/TFTP:

### MDNS Options:

LWIP_MDNS (Multicast DNS Support ** CubeMX specific **) | Disabled

### TFTP Options:

LWIP_TFTP (TFTP Support ** CubeMX specific **) | Disabled

## 5.20.9. Perf/Checks:

### Sanity Checks:

LWIP_DISABLE_TCP_SANITY_CHECKS (TCP Sanity Checks) | Disabled
LWIP_DISABLE_MEMP_SANITY_CHECKS (MEMP Sanity Checks) | Disabled

### Performance Options:

LWIP_PERF (Performace Testing for LwIP) | Disabled

## 5.20.10. Statistics:

### Debug - Statistics Options:

LWIP_STATS (Statictics Collection) | Disabled

## 5.20.11. Checksum:

### Infrastructure - Checksum Options:

CHECKSUM_BY_HARDWARE (Hardware Checksum ** CubeMX specific **) | Disabled
LWIP_CHECKSUM_CTRL_PER_NETIF (Generate/Check Checksum per Netif) | Disabled
CHECKSUM_GEN_IP (Generate Software Checksum for Outgoing IP Packets) | Disabled
CHECKSUM_GEN_UDP (Generate Software Checksum for Outgoing UDP Packets) | Disabled
CHECKSUM_GEN_TCP (Generate Software Checksum for Outgoing TCP Packets) | Disabled
CHECKSUM_GEN_ICMP (Generate Software Checksum for Outgoing ICMP Packets) | Disabled
CHECKSUM_GEN_ICMP6 (Generate Software Checksum for Outgoing ICMP6 Packets) | Disabled
CHECKSUM_CHECK_IP (Generate Software Checksum for Incoming IP Packets) | Disabled
CHECKSUM_CHECK_UDP (Generate Software Checksum for Incoming UDP Packets) | Disabled
CHECKSUM_CHECK_TCP (Generate Software Checksum for Incoming TCP Packets) | Disabled
CHECKSUM_CHECK_ICMP (Generate Software Checksum for Incoming ICMP Packets) | Disabled
CHECKSUM_CHECK_ICMP6 (Generate Software Checksum for Incoming ICMP6 Packets) | Disabled

## 5.20.12. Debug:

### LwIP Main Debugging Options:

LWIP_DBG_MIN_LEVEL (Minimum Level) | All

### * User modified value

# 6. System Configuration

# 6.1. GPIO configuration

IP | Pin | Signal | GPIO mode | GPIO pull/up pull down

## Max Speed

## User Label

ADC1 | PA0/WKUP | ADC1_IN0 | Analog mode | No pull-up and no pull-down | n/a
ADC2 | PA6 | ADC2_IN6 | Analog mode | No pull-up and no pull-down | n/a
ADC3 | PF10 | ADC3_IN8 | Analog mode | No pull-up and no pull-down | n/a
ETH | PG14 | ETH_TXD1 | Alternate Function Push Pull | No pull-up and no pull-down | Very High
*
PG13 | ETH_TXD0 | Alternate Function Push Pull | No pull-up and no pull-down | Very High
*
PG11 | ETH_TX_EN | Alternate Function Push Pull | No pull-up and no pull-down | Very High
*
PC1 | ETH_MDC | Alternate Function Push Pull | No pull-up and no pull-down | Very High
*
PA1 | ETH_REF_CLK Alternate Function Push Pull | No pull-up and no pull-down | Very High
*
PC4 | ETH_RXD0 | Alternate Function Push Pull | No pull-up and no pull-down | Very High
*
PA2 | ETH_MDIO | Alternate Function Push Pull | No pull-up and no pull-down | Very High
*
PC5 | ETH_RXD1 | Alternate Function Push Pull | No pull-up and no pull-down | Very High
*
PA7 | ETH_CRS_DV Alternate Function Push Pull | No pull-up and no pull-down | Very High
*
FMC | PG15 | FMC_SDNCAS Alternate Function Push Pull | No pull-up and no pull-down | Very High | FMC_SDNCAS
[MT48LC4M32B2B5-
6A_CAS]
PD0 | FMC_D2 | Alternate Function Push Pull | No pull-up and no pull-down | Very High | FMC_D2
[MT48LC4M32B2B5-
6A_DQ2]
PD1 | FMC_D3 | Alternate Function Push Pull | No pull-up and no pull-down | Very High | FMC_D3
[MT48LC4M32B2B5-
6A_DQ3]
PF0 | FMC_A0 | Alternate Function Push Pull | No pull-up and no pull-down | Very High | FMC_A0
[MT48LC4M32B2B5-
6A_A0]
PF1 | FMC_A1 | Alternate Function Push Pull | No pull-up and no pull-down | Very High | FMC_A1

IP | Pin | Signal | GPIO mode | GPIO pull/up pull down | Max Speed | User Label
| | | | | | [MT48LC4M32B2B5-6A_A1]
| PF2 | FMC_A2 | Alternate Function Push Pull | No pull-up and no pull-down | Very High | FMC_A2 [MT48LC4M32B2B5-6A_A2]
| PF3 | FMC_A3 | Alternate Function Push Pull | No pull-up and no pull-down | Very High | FMC_A3 [MT48LC4M32B2B5-6A_A3]
| PG8 | FMC_SDCLK | Alternate Function Push Pull | No pull-up and no pull-down | Very High | FMC_SDCLK [MT48LC4M32B2B5-6A_CLK]
| PF4 | FMC_A4 | Alternate Function Push Pull | No pull-up and no pull-down | Very High | FMC_A4 [MT48LC4M32B2B5-6A_A4]
| PH5 | FMC_SDNWE | Alternate Function Push Pull | No pull-up and no pull-down | Very High | FMC_SDNME [MT48LC4M32B2B5-6A_WE]
| PH3 | FMC_SDNE0 | Alternate Function Push Pull | No pull-up and no pull-down | Very High | FMC_SDNE0 [MT48LC4M32B2B5-6A_CS]
| PF5 | FMC_A5 | Alternate Function Push Pull | No pull-up and no pull-down | Very High | FMC_A5 [MT48LC4M32B2B5-6A_A5]
| PD15 | FMC_D1 | Alternate Function Push Pull | No pull-up and no pull-down | Very High | FMC_D1 [MT48LC4M32B2B5-6A_DQ1]
| PD10 | FMC_D15 | Alternate Function Push Pull | No pull-up and no pull-down | Very High | FMC_D15 [MT48LC4M32B2B5-6A_DQ15]
| PC3 | FMC_SDCKE0 | Alternate Function Push Pull | No pull-up and no pull-down | Very High | FMC_SDCKE0 [MT48LC4M32B2B5-6A_CKE]
| PD14 | FMC_D0 | Alternate Function Push Pull | No pull-up and no pull-down | Very High | FMC_D0 [MT48LC4M32B2B5-6A_DQ0]
| PD9 | FMC_D14 | Alternate Function Push Pull | No pull-up and no pull-down | Very High | FMC_D14 [MT48LC4M32B2B5-6A_DQ14]
| PD8 | FMC_D13 | Alternate Function Push Pull | No pull-up and no pull-down | Very High | FMC_D13 [MT48LC4M32B2B5-6A_DQ13]
| PF12 | FMC_A6 | Alternate Function Push Pull | No pull-up and no pull-down | Very High | FMC_A6 [MT48LC4M32B2B5-6A_A6]
| PF15 | FMC_A9 | Alternate Function Push Pull | No pull-up and no pull-down | Very High | FMC_A9 [MT48LC4M32B2B5-6A_A9]

IP | Pin | Signal | GPIO mode | GPIO pull/up pull down

## Max Speed

## User Label

PF13 | FMC_A7 | Alternate Function Push Pull | No pull-up and no pull-down | Very High | FMC_A7 [MT48LC4M32B2B5- 6A_A7]
PG0 | FMC_A10 | Alternate Function Push Pull | No pull-up and no pull-down | Very High | FMC_A10 [MT48LC4M32B2B5- 6A_A10]
PE8 | FMC_D5 | Alternate Function Push Pull | No pull-up and no pull-down | Very High | FMC_D5 [MT48LC4M32B2B5- 6A_DQ5]
PG5 | FMC_BA1 | Alternate Function Push Pull | No pull-up and no pull-down | Very High | FMC_BA1 [MT48LC4M32B2B5- 6A_BA1]
PG4 | FMC_BA0 | Alternate Function Push Pull | No pull-up and no pull-down | Very High | FMC_BA0 [MT48LC4M32B2B5- 6A_BA0]
PF14 | FMC_A8 | Alternate Function Push Pull | No pull-up and no pull-down | Very High | FMC_A8 [MT48LC4M32B2B5- 6A_A8]
PF11 | FMC_SDNRAS Alternate Function Push Pull | No pull-up and no pull-down | Very High | FMC_SDNRAS
| | | | | [MT48LC4M32B2B5- 6A_RAS]
PE9 | FMC_D6 | Alternate Function Push Pull | No pull-up and no pull-down | Very High | FMC_D6 [MT48LC4M32B2B5- 6A_DQ6]
PE11 | FMC_D8 | Alternate Function Push Pull | No pull-up and no pull-down | Very High | FMC_D8 [MT48LC4M32B2B5- 6A_DQ8]
PE14 | FMC_D11 | Alternate Function Push Pull | No pull-up and no pull-down | Very High | FMC_D11 [MT48LC4M32B2B5- 6A_DQ11]
PE7 | FMC_D4 | Alternate Function Push Pull | No pull-up and no pull-down | Very High | FMC_D4 [MT48LC4M32B2B5- 6A_DQ4]
PE10 | FMC_D7 | Alternate Function Push Pull | No pull-up and no pull-down | Very High | FMC_D7 [MT48LC4M32B2B5- 6A_DQ7]
PE12 | FMC_D9 | Alternate Function Push Pull | No pull-up and no pull-down | Very High | FMC_D9 [MT48LC4M32B2B5- 6A_DQ9]
PE15 | FMC_D12 | Alternate Function Push Pull | No pull-up and no pull-down | Very High | FMC_D12 [MT48LC4M32B2B5- 6A_DQ12]
PE13 | FMC_D10 | Alternate Function Push Pull | No pull-up and no pull-down | Very High | FMC_D10 [MT48LC4M32B2B5- 6A_DQ10]
I2C3 | PH7 | I2C3_SCL | Alternate Function Open
| | Drain | Pull-up | Very High | LCD_SCL [RK043FN48H- CT672B_SCL]

IP | Pin | Signal | GPIO mode | GPIO pull/up pull

## down

## Max Speed

## User Label

*
| PH8 | I2C3_SDA | Alternate Function Open Drain | Pull-up | Very High
*
| | | | | | LCD_SDA [RK043FN48H- CT672B_SDA]
LTDC | PK7 | LTDC_DE | Alternate Function Push Pull | No pull-up and no pull-down | Low | LCD_DE [RK043FN48H- CT672B_DE]
| PK6 | LTDC_B7 | Alternate Function Push Pull | No pull-up and no pull-down | Low | LCD_B7 [RK043FN48H- CT672B_B7]
| PK5 | LTDC_B6 | Alternate Function Push Pull | No pull-up and no pull-down | Low | LCD_B6 [RK043FN48H- CT672B_B6]
| PG12 | LTDC_B4 | Alternate Function Push Pull | No pull-up and no pull-down | Low | LCD_B4 [RK043FN48H- CT672B_B4]
PI10 | LTDC_HSYNC Alternate Function Push Pull | No pull-up and no pull-down | Low | LCD_HSYNC
| | | | | | [RK043FN48H- CT672B_HSYNC]
| PK4 | LTDC_B5 | Alternate Function Push Pull | No pull-up and no pull-down | Low | LCD_B5 [RK043FN48H- CT672B_B5]
| PJ15 | LTDC_B3 | Alternate Function Push Pull | No pull-up and no pull-down | Low | LCD_B3 [RK043FN48H- CT672B_B3]
PI9 | LTDC_VSYNC Alternate Function Push Pull | No pull-up and no pull-down | Low | LCD_VSYNC
| | | | | | [RK043FN48H- CT672B_VSYNC]
| PK1 | LTDC_G6 | Alternate Function Push Pull | No pull-up and no pull-down | Low | LCD_G6 [RK043FN48H- CT672B_G6]
| PK2 | LTDC_G7 | Alternate Function Push Pull | No pull-up and no pull-down | Low | LCD_G7 [RK043FN48H- CT672B_G7]
| PJ11 | LTDC_G4 | Alternate Function Push Pull | No pull-up and no pull-down | Low | LCD_G4 [RK043FN48H- CT672B_G4]
| PK0 | LTDC_G5 | Alternate Function Push Pull | No pull-up and no pull-down | Low | LCD_G5 [RK043FN48H- CT672B_G5]
| PI14 | LTDC_CLK | Alternate Function Push Pull | No pull-up and no pull-down | Low | LCD_CLK [RK043FN48H- CT672B_CLK]
| PJ10 | LTDC_G3 | Alternate Function Push Pull | No pull-up and no pull-down | Low | LCD_G3 [RK043FN48H- CT672B_G3]
| PJ9 | LTDC_G2 | Alternate Function Push Pull | No pull-up and no pull-down | Low | LCD_G2 [RK043FN48H- CT672B_G2]
| PJ6 | LTDC_R7 | Alternate Function Push Pull | No pull-up and no pull-down | Low | LCD_R7 [RK043FN48H- CT672B_R7]
| PJ4 | LTDC_R5 | Alternate Function Push Pull | No pull-up and no pull-down | Low | LCD_R5 [RK043FN48H- CT672B_R5]
| PJ5 | LTDC_R6 | Alternate Function Push Pull | No pull-up and no pull-down | Low | LCD_R6 [RK043FN48H- CT672B_R6]
| PJ3 | LTDC_R4 | Alternate Function Push Pull | No pull-up and no pull-down | Low | LCD_R4 [RK043FN48H- CT672B_R4]
| PJ2 | LTDC_R3 | Alternate Function Push Pull | No pull-up and no pull-down | Low | LCD_R3 [RK043FN48H-

IP | Pin | Signal | GPIO mode | GPIO pull/up pull down | Max Speed | User Label
| | | | | | CT672B_R3]
QUADSPI | PE2 | QUADSPI_BK1_I O2 | Alternate Function Push Pull | No pull-up and no pull-down | Very High * | QSPI_D2 [N25Q128A13EF840E_DQ 2]
| PB6 | QUADSPI_BK1_ NCS | Alternate Function Push Pull | No pull-up and no pull-down | Very High * | QSPI_NCS [N25Q128A13EF840E_S]
| PB2 | QUADSPI_CLK | Alternate Function Push Pull | No pull-up and no pull-down | Very High *
| PD12 | QUADSPI_BK1_I O1 | Alternate Function Push Pull | No pull-up and no pull-down | Very High * | QSPI_D1 [N25Q128A13EF840E_DQ 1]
| PD13 | QUADSPI_BK1_I O3 | Alternate Function Push Pull | No pull-up and no pull-down | Very High * | QSPI_D3 [N25Q128A13EF840E_DQ 3]
| PD11 | QUADSPI_BK1_I O0 | Alternate Function Push Pull | No pull-up and no pull-down | Very High * | QSPI_D0 [N25Q128A13EF840E_DQ 0]
RCC | PH0/OSC_I N | RCC_OSC_IN | n/a | n/a | n/a | OSC_25M [NZ2520SB-25.00M_OUT]
| PH1/OSC_O UT | RCC_OSC_OUT | n/a | n/a | n/a
SAI2 | PI4 | SAI2_MCLK_A | Alternate Function Push Pull | No pull-up and no pull-down | Low | SAI2_MCLKA [WM8994ECS/R_MCLK1]
| PI5 | SAI2_SCK_A | Alternate Function Push Pull | No pull-up and no pull-down | Low | SAI2_SCKA [WM8994ECS/R_BCLK1]
| PI7 | SAI2_FS_A | Alternate Function Push Pull | No pull-up and no pull-down | Low | SAI2_FSA [WM8994ECS/R_LRCLK1]
| PI6 | SAI2_SD_A | Alternate Function Push Pull | No pull-up and no pull-down | Low | SAI2_SDA [WM8994ECS/R_DACDAT 1]
SDMMC1 | PC12 | SDMMC1_CK | Alternate Function Push Pull | No pull-up and no pull-down | Very High | SDMMC_CK
| PC11 | SDMMC1_D3 | Alternate Function Push Pull | No pull-up and no pull-down | Very High | SDMMC_D3
| PC10 | SDMMC1_D2 | Alternate Function Push Pull | No pull-up and no pull-down | Very High | SDMMC_D2
| PD2 | SDMMC1_CMD | Alternate Function Push Pull | No pull-up and no pull-down | Very High | SDMMC_D0
| PC9 | SDMMC1_D1 | Alternate Function Push Pull | No pull-up and no pull-down | Very High
| PC8 | SDMMC1_D0 | Alternate Function Push Pull | No pull-up and no pull-down | Very High
SPI2 | PD3 | SPI2_SCK | Alternate Function Push Pull | No pull-up and no pull-down | Very High *
| PI3 | SPI2_MOSI | Alternate Function Push Pull | No pull-up and no pull-down | Very High *
TIM5 | PH11 | TIM5_CH2 | Alternate Function Push Pull | No pull-up and no pull-down | Low
| PH10 | TIM5_CH1 | Alternate Function Push Pull | No pull-up and no pull-down | Low
TIM14 | PF9 | TIM14_CH1 | Alternate Function Push Pull | No pull-up and no pull-down | Low

IP | Pin | Signal | GPIO mode | GPIO pull/up pull down | Max Speed | User Label
USART1 | PB7 | USART1_RX | Alternate Function Push Pull | * | Low | VCP_RX [STM32F103CBT6_PA2]
| PA9 | USART1_TX | Alternate Function Push Pull | * | Low | VCP_TX [STM32F103CBT6_PA3]
| PE4 | LTDC_B0 | Alternate Function Push Pull | No pull-up and no pull-down | Low | LCD_B0 [RK043FN48H-CT672B_B0]
| PE1 | FMC_NBL1 | Alternate Function Push Pull | No pull-up and no pull-down | Very High | FMC_NBL1 [MT48LC4M32B2B5-6A_DQM1]
| PE0 | FMC_NBL0 | Alternate Function Push Pull | No pull-up and no pull-down | Very High | FMC_NBL0 [MT48LC4M32B2B5-6A_DQM0]
| PB3 | SYS_JTDO-SWO | n/a | n/a | n/a | SWO
| PA14 | SYS_JTCK-SWCLK | n/a | n/a | n/a | SWCLK
| PA13 | SYS_JTMS-SWDIO | n/a | n/a | n/a | SWDIO
| PJ13 | LTDC_B1 | Alternate Function Push Pull | No pull-up and no pull-down | Low | LCD_B1 [RK043FN48H-CT672B_B1]
| PI8 | RTC_TS | n/a | n/a | n/a | NC1 [TP2]
| PG10 | SAI2_SD_B | Alternate Function Push Pull | No pull-up and no pull-down | Low | SAI2_SDB [WM8994ECS/R_ADCDAT 1]
| PJ14 | LTDC_B2 | Alternate Function Push Pull | No pull-up and no pull-down | Low | LCD_B2 [RK043FN48H-CT672B_B2]
| PI15 | LTDC_R0 | Alternate Function Push Pull | No pull-up and no pull-down | Low | LCD_R0 [RK043FN48H-CT672B_R0]
| PJ8 | LTDC_G1 | Alternate Function Push Pull | No pull-up and no pull-down | Low | LCD_G1 [RK043FN48H-CT672B_G1]
| PJ7 | LTDC_G0 | Alternate Function Push Pull | No pull-up and no pull-down | Low | LCD_G0 [RK043FN48H-CT672B_G0]
| PG1 | FMC_A11 | Alternate Function Push Pull | No pull-up and no pull-down | Very High | FMC_A11 [MT48LC4M32B2B5-6A_A11]
| PJ0 | LTDC_R1 | Alternate Function Push Pull | No pull-up and no pull-down | Low | LCD_R1 [RK043FN48H-CT672B_R1]
| PJ1 | LTDC_R2 | Alternate Function Push Pull | No pull-up and no pull-down | Low | LCD_R2 [RK043FN48H-CT672B_R2]
GPIO | PE3 | GPIO_Input | Input mode | Pull-up * | n/a | KEY_SYNC_OUT
| PB8 | GPIO_Output | Output Push Pull | No pull-up and no pull-down | Medium * | LED_ENC
| PB4 | GPIO_Input | Input mode | Pull-down * | n/a | PAD_3
| PD7 | GPIO_Input | Input mode | Pull-up * | n/a | KEY_BACK
| PA15 | GPIO_Output | Output Push Pull | No pull-up and no pull-down | Medium * | LED_PRESET

Single
Mapped
Signals

IP | Pin | Signal | GPIO mode | GPIO pull/up pull down | Max Speed | User Label
| PB9 | GPIO_Input | Input mode | Pull-up * | n/a | KEY_EDIT
| PJ12 | GPIO_Input | Input mode | No pull-up and no pull-down | n/a | OTG_FS_VBUS
| PD5 | GPIO_Output | Output Push Pull | No pull-up and no pull-down | Medium * | LED_SYNC_OUT
| PI2 | GPIO_Input | Input mode | Pull-down * | n/a | PAD_7
| PA11 | GPIO_Output | Output Push Pull | No pull-up and no pull-down | Medium * | LED_EFFECT
| PC13 | GPIO_Input | Input mode | No pull-up and no pull-down | n/a | uSD_Detect
| PK3 | GPIO_Output | Output Push Pull | No pull-up and no pull-down | Low | LCD_BL_CTRL [STLD40DPUR_EN]
| PD4 | GPIO_Input | Input mode | Pull-up * | n/a | KEY_EFFECT
| PI1 | GPIO_Output | Output Push Pull | No pull-up and no pull-down | Medium * | LED_EDIT
| PI12 | GPIO_Output | Output Push Pull | No pull-up and no pull-down | Low | LCD_DISP [RK043FN48H-CT672B_DISP]
| PI0 | GPIO_Input | Input mode | Pull-down * | n/a | PAD_5
| PA8 | GPIO_Input | Input mode | Pull-up * | n/a | KEY_PRESET
| PI13 | GPIO_EXTI13 | External Event Mode with Rising edge trigger detection * | No pull-up and no pull-down | n/a | LCD_INT
| PC7 | GPIO_Input | Input mode | Pull-down * | n/a | PAD_0
| PC6 | GPIO_Input | Input mode | Pull-down * | n/a | PAD_1
| PG7 | GPIO_Input | Input mode | Pull-down * | n/a | PAD_4
| PG6 | GPIO_Input | Input mode | Pull-down * | n/a | PAD_2
| PF7 | GPIO_Input | Input mode | Pull-up * | n/a | KEY_MENU
| PF6 | GPIO_Input | Input mode | Pull-up * | n/a | KEY_ENC
| PF8 | GPIO_Output | Output Push Pull | No pull-up and no pull-down | Medium * | LED_MENU
| PG3 | GPIO_Output | Output Push Pull | No pull-up and no pull-down | Low | EXT_RST
| PG2 | GPIO_Input | Input mode | No pull-up and no pull-down | n/a | RMII_RXER
| PH6 | GPIO_Input | Input mode | Pull-down * | n/a | PAD_6
| PB14 | GPIO_Input | Input mode | Pull-up * | n/a | KEY_SHIFT
| PB15 | GPIO_Output | Output Push Pull | No pull-up and no pull-down | Medium * | LED_SHIFT

# 6.2. DMA configuration

DMA request | Stream | Direction | Priority
SPI2_TX | DMA1_Stream4 | Memory To Peripheral | Low

## SPI2_TX: DMA1_Stream4 DMA request Settings:

Mode: | Normal
Use fifo: | Disable
Peripheral Increment: | Disable
Memory Increment: | Enable *
Peripheral Data Width: | Byte
Memory Data Width: | Byte

# 6.3. NVIC configuration

Interrupt Table | Enable | Preenmption Priority | SubPriority
Non maskable interrupt | true | 0 | 0
Hard fault interrupt | true | 0 | 0
Memory management fault | true | 0 | 0
Pre-fetch fault, memory access fault | true | 0 | 0
Undefined instruction or illegal state | true | 0 | 0
System service call via SWI instruction | true | 0 | 0
Debug monitor | true | 0 | 0
Pendable request for system service | true | 0 | 0
System tick timer | true | 0 | 0
DMA1 stream4 global interrupt | true | 0 | 0
TIM2 global interrupt | true | 2 | 0
USART1 global interrupt | true | 7 | 0
TIM5 global interrupt | true | 3 | 0
SAI2 global interrupt | true | 1 | 0
PVD interrupt through EXTI line 16 | unused
Flash global interrupt | unused
RCC global interrupt | unused
ADC1, ADC2 and ADC3 global interrupts | unused
SPI2 global interrupt | unused
TIM8 trigger and commutation interrupts and TIM14 global interrupt | unused
FMC global interrupt | unused
SDMMC1 global interrupt | unused
Ethernet global interrupt | unused
Ethernet wake-up interrupt through EXTI line 19 | unused
I2C3 event interrupt | unused
I2C3 error interrupt | unused
FPU global interrupt | unused
LTDC global interrupt | unused
LTDC global error interrupt | unused
DMA2D global interrupt | unused
QUADSPI global interrupt | unused

### * User modified value

# 7. Power Consumption Calculator report

### 7.1. Microcontroller Selection

Series | STM32F7
Line | STM32F7x6
MCU | STM32F746NGHx
Datasheet | 027590_Rev4

### 7.2. Parameter Selection

Temperature | 25
Vdd | 3.3

# 8. Software Project

## 8.1. Project Settings

Name | Value
Project Name | F7
Project Folder | C:\Keil_v5\Projects\Sampler
Toolchain / IDE | MDK-ARM V5
Firmware Package Name and Version | STM32Cube FW_F7 V1.7.0

## 8.2. Code Generation Settings

Name | Value
STM32Cube Firmware Library Package | Copy all used libraries into the project folder
Generate peripheral initialization as a pair of '.c/.h' files | Yes
Backup previously generated files when re-generating | No
Delete previously generated files when not re-generated | Yes
Set all free pins as analog (to optimize the power consumption) | No

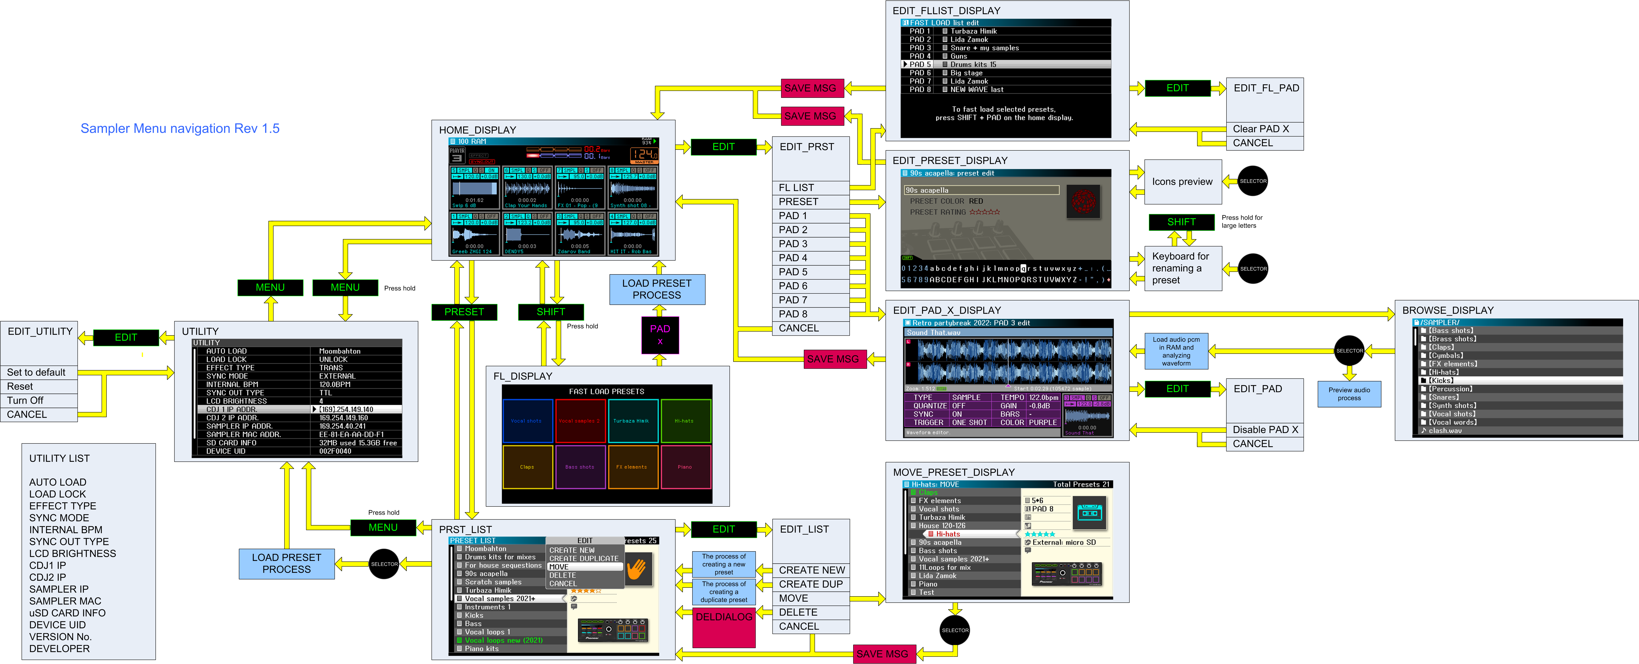
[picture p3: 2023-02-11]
Menu navigation.png

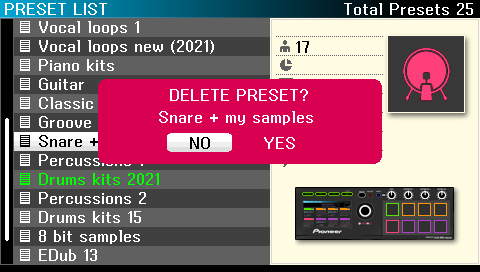
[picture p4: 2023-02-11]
Screenshots/SCREEN_475.bmp

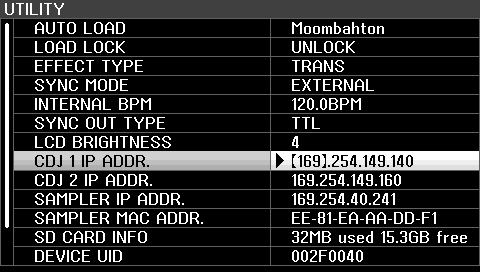
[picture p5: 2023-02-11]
Screenshots/SCREEN_749.bmp

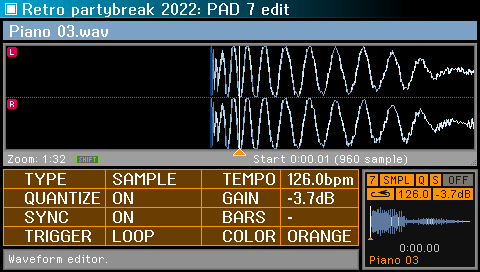
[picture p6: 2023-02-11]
Screenshots/SCREEN_124.bmp

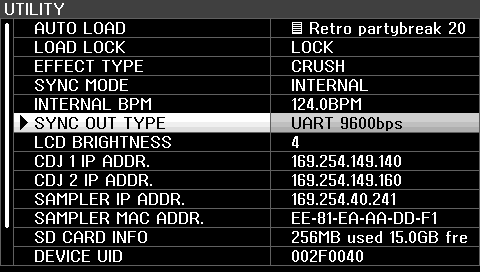
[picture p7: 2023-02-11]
Screenshots/SCREEN_414.bmp

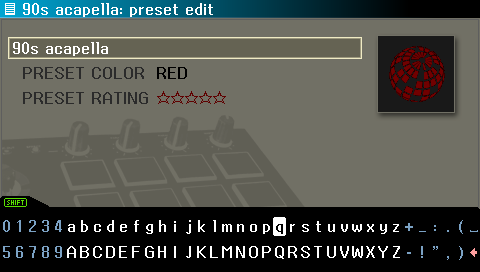
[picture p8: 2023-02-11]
Screenshots/SCREEN_195.bmp

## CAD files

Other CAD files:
CNC FILES/Encoder leds/36.4.dwg
CNC FILES/Encoder plexiglass/41mm.dwg
CNC FILES/Encoder plexiglass/detail 2/20.5mm.dwg
CNC FILES/Encoder plexiglass/detail 3/36mm + stift.dwg
CNC FILES/Encoder leds/41.dwg
CNC FILES/Encoder plexiglass/36mm.dwg
CNC FILES/Encoder plexiglass/detail 3/7mm.dwg
CNC FILES/Encoder plexiglass/20mm.dwg

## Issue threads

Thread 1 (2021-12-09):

ProDJ Link support for CDJ1000 New life?

mdethmers, 2021-12-09:
hey man, im super impressed by what you are able to achieve with all this reverse engineering from pioneer equipment. also very impressed with your ProDJ link support.

As you are using the same Discovery board for the sampler as you do for the CDJ1000 mod, do you say it would be possible to support ProDJ link support to the cdj1000 firmware? I have two of those cdj1000 NL players, and with prodj link support, it would be possible to sync bpm with my xdj700 players!

is it a matter of copy-pasting the sampler firmware over to the cdj firmware? if you want to share your code I might be able to figure it our myself and update you once I have a working copy :)

djgreeb, 2021-12-10:
Hey! I think that the CDJ-1000mk3 project, on the 32F746G board, will not be able to support prodj link with full compliance with the standard. Some of the gpio pins that are needed for ETH-PHY are already involved there. There is also too little memory on the board.
If you want to connect 2 cdj-1000mk3, based on 32F746G and you do not need to connect them to CDJ-2000s and send files, you can connect the players using uart for synchronization.
I'll add the sampler source code later.

Closed 2023-02-09.

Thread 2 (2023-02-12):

Remove Pioneer Branding

terdinatore, 2023-02-12:
Hey Andrei,

I do really love what you do with this project.

I would like to suggest removing all the Pioneer branding since it could provoke legal action from AlphaTheta Corp. and prevent you from continuing working on this in the future.

Best regards,

djgreeb, 2023-02-12:
Hi. Thank you! Where do you propose to remove the brand? On the hull? from the firmware source codes? I don't plan to make any more instances of the sampler. And I made mine with such a brand with style that my setup looked like one (cdj-2000nxs and djm-900nxs). I have no plans to compete with Pioneer Dj or hurt their business in any way. Those wishing to make the same sampler do not need to repeat all the inscriptions on the device.

terdinatore, 2023-02-12:
I am no lawyer, but in my humble opinion you should be fine having your personal sampler using any design you like.

What I would remove:
- No videos from your personal units that show the Pioneer livery.
- Remove Pioneer Logos from Firmware
- Remove/Edit any Photographs in this repo showing the Pioneer logo on the device.

While I wish such incredible DJ gear existed and Pioneer would see this and get inspired, I hope that they don't see it and set their attorneys on you.

Closed 2023-02-12.

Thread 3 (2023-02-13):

Wire Diagram / schematic

kefkevm, 2023-02-13:
Hi,

Do you have a wire diagram or electric schamatic?

greetz

djgreeb, 2023-02-13:
Hi!
There is no finished circuit so that I can publish it. Maybe later I will find time and draw up a diagram. In the meantime, you can define the connection points for the pads, buttons, and encoder in the CubeMx project or in the Firmware/Sampler/F7.pdf file. Signal names correspond to connected buttons and LEDs.

[https://github.com/djgreeb/Sampler-DJS-500/blob/main/Firmware/Sampler/F7.pdf](url)

Closed 2023-02-15.

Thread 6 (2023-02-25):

Missing File's ?

kefkevm, 2023-02-25:
Hi,

It looks like some files are missing?
See the screenshot's i took.

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

djgreeb, 2023-02-25:
https://drive.google.com/file/d/18DZ3agTO7aAusT0o3a3R0Xqb5H65mn98/view?usp=sharing

kefkevm, 2023-03-01:
Thanks a Lot,

I think it worked, but don't  have te full license for compiling..
do you have maybe a compiled .hex version as wel?

Thanks so far :)

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

ultraw3ird, 2023-12-13:
Hi, any future plans for releasing compiled fw? Unofrtunately without licensed Keil there is no way to get fw compiled due to size of project :/

kefkevm, 2024-01-02:
you have to upload the f7.hex file to the board. that's the compiled version.

ultraw3ird, 2024-01-05:
Got it, have you managed get the fw running ? mine is stuck in reset loop after uploading, probably some hw mod of board needed ?

kefkevm, 2024-01-08:
yes, you have to modify the backlight. remove R85, detach input from D8(PK3) and connect driver input to L2 (PF9). L2 = A2 in het connection pins. see the picture below.

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

ultraw3ird, 2024-01-10:
Works flawlessly. Only for info am I blind as usual and is this info written somewhere in available docs or you got this determined from CPU pinout and code ? Thanks you again for your support :)

kefkevm, 2024-01-14:
yes, you can connect directly to me. send me a DM https://www.instagram.com/feest_dj_kevin/

mattpstv, 2025-07-14:
> Works flawlessly. Only for info am I blind as usual and is this info written somewhere in available docs or you got this determined from CPU pinout and code ?

@ultraw3ird did you ever go any further with this conversation? I am also blind and curious how @kefkevm came to this solution.

 I did manage to get the firmware loaded (on two different stm32f746g-disco boards), and I see the splash screen, then an alert about no SD card found (unless I have an SD inserted), and then the main interface screen showing PLAYER 3 and "sampler preset 004" - but that's as far as I get. the track info boxes, BPM, and PRO DJ LINK remain unpopulated. I'm going by this video for what I assume us supposed to happen if hex file is uploaded correctly: https://youtu.be/rUySWEsYK1w

im hesitant to start breadboarding the pads, encoder and pots etc. until I know that I at least have a functional board.

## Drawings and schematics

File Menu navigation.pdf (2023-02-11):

## Sampler Menu navigation Rev 1.5

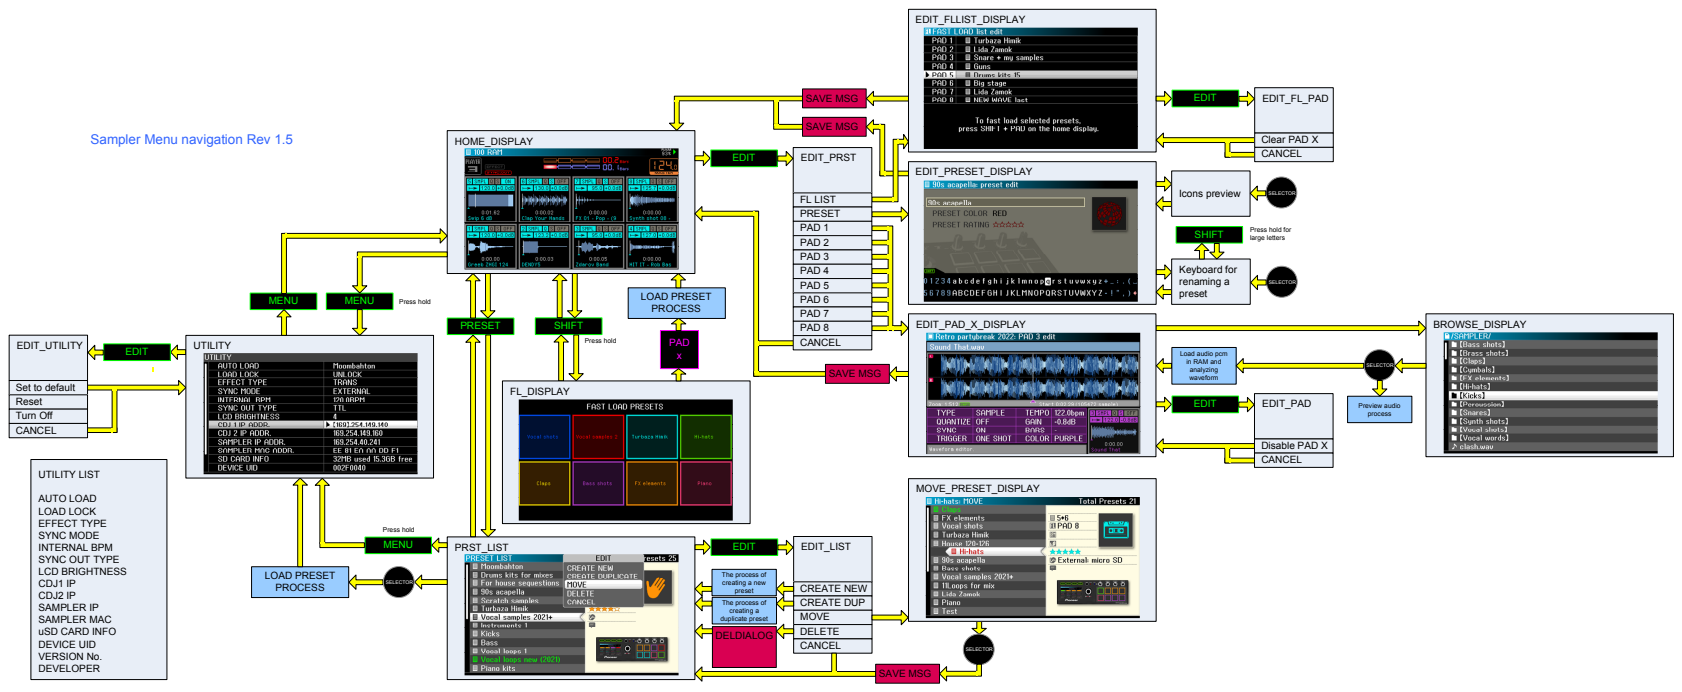
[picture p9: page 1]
PRESET; SHIFT; HOME_DISPLAY; PRST_LIST; Press hold; PAD; LOAD PRESET PROCESS; EDIT; MENU; EDIT_PRST; EDIT_LIST; CREATE NEW; CREATE DUP; MOVE; DELETE; CANCEL; EDIT_PRESET_DISPLAY; SELECTOR; EDIT_FLLIST_DISPLAY; Preview audio process; BROWSE_DISPLAY; FL LIST; PAD 1; PAD 2; PAD 3; PAD 4; PAD 5; PAD 6; PAD 7; PAD 8; Keyboard for renaming a preset; SAVE MSG; EDIT_FL_PAD; Clear PAD X; Press hold for large letters; Icons preview; EDIT_PAD; EDIT EDIT_UTILITY; UTILITY LIST; Disable PAD X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

Load audio pcm
in RAM and
analyzing
waveform

Set to default
Reset
Turn Off
CANCEL

AUTO LOAD
LOAD LOCK
EFFECT TYPE
SYNC MODE
INTERNAL BPM
SYNC OUT TYPE
LCD BRIGHTNESS
CDJ1 IP
CDJ2 IP
SAMPLER IP
SAMPLER MAC
uSD CARD INFO
DEVICE UID
VERSION No.
DEVELOPER

The process of
creating a new
preset

creating a
duplicate preset
DELDIALOG

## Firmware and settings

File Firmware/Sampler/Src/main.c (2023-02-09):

/**
  ******************************************************************************
  * File Name          : main.c
  * Description        : Main program body
  ******************************************************************************
  * This notice applies to any and all portions of this file
  * that are not between comment pairs USER CODE BEGIN and
  * USER CODE END. Other portions of this file, whether 
  * inserted by the user or by software development tools
  * are owned by their respective copyright owners.
  *
  * Copyright (c) 2022 STMicroelectronics International N.V. 
  * All rights reserved.
  *
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
  ******************************************************************************
  */
/* Includes ------------------------------------------------------------------*/
#include "main.h"
#include "stm32f7xx_hal.h"
#include "adc.h"
#include "dma.h"
#include "dma2d.h"
#include "fatfs.h"
#include "i2c.h"
#include "ltdc.h"
#include "lwip.h"
#include "quadspi.h"
#include "sai.h"
#include "sdmmc.h"
#include "spi.h"
#include "tim.h"
#include "usart.h"
#include "gpio.h"
#include "fmc.h"

/* USER CODE BEGIN Includes */

/////////////////////////////////////////////////////////////////////////////////////////////////////////////
//
//		This firmware for F7 chip, 32F746G DISCOVERY board.
//		Added support for some Rekordbox functions, display of static and dynamic waveform, audio interpolation process. 
//
//		Added support for control buttons with led backlight.
//		IMPORTANT!!! 
//		After regenerating the code with Cube, make these corrections:
//		File sai.c
//		 - hsai_BlockA2.FrameInit.ActiveFrameLength = 32;
//
//		File dma2d.c, comment 2 lines:
//		 - //  hdma2d.LayerCfg[1].AlphaInverted = DMA2D_REGULAR_ALPHA;
//		 - //  hdma2d.LayerCfg[1].RedBlueSwap = DMA2D_RB_REGULAR;
//
//		File arm_math.h, add line:
//		 - #define ARM_MATH_CM7
//		init this functions after LCD_Layers initialization:	
//
//		Copy from backup this files:
//					- ethernetif.c
//					- ethernetif.h
//					- lwip.c
//					- lwip.h
//					- copy folder FatFs and FatFs files
//  	
//		
//			File \F7 XDJ_PANEL\Drivers\BSP\STM32746G-Discovery\stm32746g_discovery_lcd.c
//				- //HAL_GPIO_WritePin(LCD_BL_CTRL_GPIO_PORT, LCD_BL_CTRL_PIN, GPIO_PIN_SET);      //300 line
//
//
//  		File main.c CHANGE VALUE PeriphClkInitStruct.PLLI2S.PLLI2SN = 271;			//135 old
//
//			Delete MX_LWIP_Init() in TOP!
//
//		Compilator settings:	
//
//--c99 -c --cpu Cortex-M7.fp.sp -D__MICROLIB -g -O1 --apcs=interwork --split_sections -I../Inc -I../Drivers/STM32F7xx_HAL_Driver/Inc -I../Drivers/STM32F7xx_HAL_Driver/Inc/Legacy -I../Drivers/CMSIS/Device/ST/STM32F7xx/Include -I../Drivers/CMSIS/Include -I..\Drivers\BSP\STM32746G-Discovery -I..\Drivers\BSP\Components\rk043fn48h -I..\Drivers\BSP\Components\Common -I..\Utilities\CPU -I..\Utilities\Fonts -I..\Utilities\Log -I../Middlewares/Third_Party/FatFs/src/drivers -I../Middlewares/Third_Party/FatFs/src --C99 
//-I "C:\Keil_v5\My_Project\F7 XDJ_PANEL\MDK-ARM\RTE" 
//-I C:\Keil_v5\ARM\PACK\ARM\CMSIS\4.5.0\CMSIS\Include 
//-I C:\Keil_v5\ARM\PACK\Keil\STM32F7xx_DFP\2.11.0\Drivers\CMSIS\Device\ST\STM32F7xx\Include 
//-D__UVISION_VERSION="517" -D_RTE_ -DSTM32F746xx -DUSE_HAL_DRIVER -DSTM32F746xx -o "F7\*.o" --omf_browse "F7\*.crf" --depend "F7\*.d" 
//
//		generated by:
//			STM32CubeMX 4.22.0
//			STM32Cube FW_F7 V1.7.0
//
//////////////////////////////////////////////////////////////////////////////////////////////////////////////
//
//	ver. 0.35
//		- added all periph buttons, leds, VRs and encoder
//	ver. 0.36
//		- added buttons handler
//	ver. 0.37
//		- added USB USART debug code
//		- added first service mode 
//	ver. 0.38
//		- improved encoder noise canceller code
//	ver. 0.41
//		- added service mode code parts
//		-	added ADCs VRs code with hysteresis and filter
//	ver. 0.45
//		- added service mode code parts
//	ver. 0.46
//		- fixed SERVICE MODE code
//	ver. 0.47
//		- added sync out led blink
//	ver. 0.48
//		- the signals from the pads are inverted, the pullups are replaced with pulldowns. It is also changed in the hardware
//	ver. 0.49
//		-	added PWM backlight
//	ver. 0.51
//		-	added PRESETS select display
//	ver. 0.53
//		-	added reading preset preview pads color, rating
//		-	added loading presets from preset list
//		-	added long blink encoder led if the preset is loaded for a very long time 
//	ver. 0.54
//		-	added color instruments icons
//		-	added shadow at the rating stars
//	ver. 0.57
//		-	added sync pitch 
//		-	added imitate deck mode
//		- added blink pads
//	ver. 0.61
//		-	added dynamic timeline on waveforms 
//		-	added colored CUE points and colored samle name
//	ver. 0.63
//		-	added first sequencer
//	ver. 0.65
//		-	minor fixes for the GUI sequencer
//		- added status bar with playback status
//		- added icons for effect and sync. out
//	ver. 0.67
//		-	added on-off pads label
//	ver. 0.68
//		-	minor fixes GUI
//	ver. 0.70
//		-	fixed pad1 RGB led problem
//		-	minor fixes
//	ver. 0.72
//		-	minor GUI fixes
//		- added UTILITY window
//		- added master bpm shield
//	ver. 0.73
//		- added timestamp for pads press moments and filter 
//		-	added ATT_LV for pads
//	ver. 0.74
//		- changed "+" symbol in 15P font
//		-	minol fixes in gui preset list
//		-	added gui.h and audio.h
//	ver. 0.77
//		- added EDIT PRESER window
//		- changed SYNC OUT and EFFECT GUI gray color
//	ver. 0.79
//		- improved debug mode
//		- added interrupt for received uart
//	ver. 0.80
//		-	added processing to the EDIT for the encoder button
//		- changed project structure main.c file is split into many * .h files
//	ver. 0.81
//		-	added preset list edit menu
//	ver. 0.87
//		-	added DELETE DIALOG
//		-	added encoder_handler.h, key_handler.h
//		- improved  DELETE DIALOG
//		-	added noise filter for encoder button
//	ver. 0.88
//		- fixed fixed bugs in GUI UTILITY
//		- improved GUI preset list
//		- improved the mechanism for creating screenshots, using both layers
//	ver. 0.89
//		- improved configuration in ffconf.h
//	ver. 0.90
//		- improved preset list gui
//	ver. 0.91
//		- improved UTILITY
//		- add edit pad display, edit preset display, edit FL display
//	ver. 0.94
//		- improved UTILITY id address set
//	ver. 0.98
//		- added utility edit menu
//		- added internal bpm generator
//	ver. 1.06
//		- added write uSD prc
//	ver. 1.09
//		- added edit preset display
//		- added write preset uSD prc 
//		- added keyboard and rename prc		
//		- added keyboard animation	
//	ver. 1.17
//		- added blinking cursor for kyeboard
//		- added waveform editor
//		- improved edit pad display gui
//		- improved home display gui
//		- added simple waveform analyzer
//	ver. 1.19
//		- improved edit pad display
//		- added prompt for edit pad display
//		- added prompt for edit preset display
//		- added first BROWSER display
//	ver. 1.23
//		- replaced FATFS lib! (previous lib not work USE_LFN for READDIR)
//	ver. 1.25
//		- fixed display of sample names inside folders. Folder removed from title bar
//		- fixed edit pad GUI bugs
//		- added realtime pad color update when editing a pad
//	ver. 1.26
//		- fixed ethernetif.c beat process for external sync
//		- added FLLIST_DISPLAY
//	ver. 1.28
//		- added sequence editor
//	ver. 1.31
//		-	minor fixes
//		-	added [folder] style in BROWSER display
//		-	added dynamic pad in edit pad display gui
//	ver. 1.33
//		-	added first FL presets animation
//	ver. 1.34
//		-	improved FL presets animation
//	ver. 1.35
//		-	added "create new preset" and "create duplicate" process
//	ver. 1.36
//		-	improved "create new preset" and "create duplicate" process
//		- added "preset list is full" and "error x" msg
//		- added automaticly wzoom for waveform
//	ver. 1.37
//		- added noise filters for buttons PRESET, SHIFT, EDIT, BACK, EFFECT
//	ver. 1.39
//		-	added delete prc
//		- fixed display of MAC-address in service mode
//	ver. 1.40
//		- fixed delete prc
//	ver. 1.42
//		- work on the edit fl list
//	ver. 1.43
//		- new FL preset load animation
//	ver. 1.44
//		- added background picture on edit preset display
//		- added FIR filter in WFMCREATE()
//	ver. 1.47
//		-	improved WFMCREATE(), FIR and analising algorythm
//		- the algorithm for displaying a big waveform has been changed
//		-	added a mechanism for creating a template Presets.pst file on an empty sd card
//	ver. 1.48
//		-	changed color map for big waveform (colors from cdj dump)
//	ver. 1.51
//		-	fixed a bug: where inactive pads in the edit_pad_display would start glowing after the pad_x being edited was stopped
//		-	improved edit_pad_display
//	ver. 1.55
//		-	bug fixes in the function REDRAW_PAD_EDIT()
//		- added first move preset display
//	ver. 1.56
//		-	bug fixes in the MOVE_PRESET	
//		-	first move_preser_prc
//	ver. 1.57
//		-	improved move_preser_prc	
//	ver. 1.59
//		-	bug fixes in the function REDRAW_PAD_EDIT()
//		-	added new icons for presets
//	ver. 1.60
//		-	added new icons for presets
//	ver. 1.61
//		-	changed PLL frequency multiplier PeriphClkInitStruct.PLLI2S.PLLI2SN = 271 (135 old)
//	ver. 1.65
//		-	quantize first
//	ver. 1.68
//		-	improved quantize process
//		-	minor fixes
//		-	added first effects
//	ver. 1.69
//		-	improved trans effect process
//	ver. 1.70
//		-	optimized and improved trans effect process
//	ver. 1.71
//		-	added ram fill percentage status
//	ver. 1.73
//		-	optimized HAL_SAI_Transmit_IT
//		-	added uart sync out signal
//	ver. 1.74
//		-	bug fixed in audio handler limiting play_adr size at 0xFFFFF
//		- added errors descriptor
//		-	bug fixed in waveform color draw_st_wvfm()
//	ver. 1.75
//		- changed the principle of operation of SPI2 for PADS LEDs. Now SPI2 works via DMA.
//	ver. 1.77
//		- improved performance of Moog Filter and LPF
//
//////////////////////////////////////////////////////////////////////////////////////////////////////////////


#include <stdlib.h>
#include <string.h>
#include <stdio.h>
#include "stm32746g_discovery.h"
#include "stm32746g_discovery_lcd.h"
//#include "ff.h"
#include "wm8994.h"


/* USER CODE END Includes */


/* USER CODE BEGIN PV */
#include <math.h>
#include "arm_math.h"
#include "skins.h"
#include "logo.h"
#include "ft5336.h"
#include "stm32746g_discovery_qspi.h"
#include "lwip/udp.h"
#include "net.h"

#include "global_variables.h"


char FIRMWARE_VERSION[] = "1.77";								
/* USER CODE END PV */

void SystemClock_Config(void);

/* USER CODE BEGIN PFP */

/* USER CODE END PFP */

/* USER CODE BEGIN 0 */
void GET_SD_INFO(void);								//check used and free memory on sd card
#include "dac.h"
void ReDrawScroll(uint16_t total_elements, uint16_t current_element_pos);
void COLOR_SET(uint32_t color, uint8_t LD);									//set colors for PADS in color ram	
uint8_t LOAD_PRESET_LIST(void);															//load presets list, utility. return error
uint8_t LOAD_PRESET(uint8_t pst_num);												//load preset. return error
void PREPARE_ERR_MSG(uint8_t er);														//prepare error message string
uint8_t LOAD_ONE_PAD(uint8_t pst_num);											//load one pad for pad edit. return error
void SwitchInformationLayer(uint8_t LAY);										//Switch display layers
#include "utility.h"	
void intDrawTriangle(uint8_t CCP); 																//draw triangle for browser with INFO
void NAVIGATOR(uint8_t UPDOWN);																		//Navigate preset list, UTILITY and other
uint16_t CREATE_SCREEN(void);																			//univrsal function for creating current screenshots. return screen number
void int_DRAW_STARS_RATING(uint8_t rat, uint8_t rat_color, uint8_t pos);	//draw rating in preset list
void int_DRAW_ICO(uint8_t ICO_NUMB, uint8_t col, uint8_t pos);		//draw icons
void int_pad_handler(uint8_t PAD);																//internal for pads
void Draw_Static_Pads(void);																			//draw static gui pads for home display
void REDRAW_PAD(uint8_t pad);																			//redraw dynamic pad's GUI
void REDRAW_PAD_EDIT(uint8_t pad);																//redraw dynamic pad's in GUI edit pad
void CREATE_GUI_STYLE_COLOR(uint32_t color);											//create gui table color
uint32_t CREATE_PIC_COLOR(uint32_t col);													//create color for picture

#include "edit_fl_list.h"
#include "fat_process.h"
#include "waveformanalyzer.h"
#include "sync_mode_upd.h"
#include "edit_list_gui.h"
#include "edit_preset_gui.h"
#include "delete_dialog_gui.h"
#include "guifunc.h"
#include "edit_pad_display.h"
#include "audio_handler.h"
#include "service_mode.h"
#include "edit_preset_display.h"
#include "keyboard.h"
#include "browser.h"
#include "key_handler.h"
#include "encoder_handler.h"
#include "preset_list.h"
#include "move_preset.h"
#include "edit_utility_gui.h"
#include "slide_fl_pads.h"



/* USER CODE END 0 */

int main(void)
{

  /* Enable I-Cache-------------------------------------------------------------*/
  SCB_EnableICache();

  /* Enable D-Cache-------------------------------------------------------------*/
  SCB_EnableDCache();

  /* MCU Configuration----------------------------------------------------------*/

  /* Reset of all peripherals, Initializes the Flash interface and the Systick. */
  HAL_Init();

  /* Configure the system clock */
  SystemClock_Config();

  /* Initialize all configured peripherals */
  MX_GPIO_Init();
  MX_DMA_Init();
  MX_DMA2D_Init();
  MX_FMC_Init();
  MX_LTDC_Init();
  MX_SDMMC1_SD_Init();
  MX_FATFS_Init();
  MX_I2C3_Init();
  MX_SAI2_Init();
  MX_QUADSPI_Init();
  MX_USART1_UART_Init();
  //MX_LWIP_Init();
  MX_TIM2_Init();
  MX_SPI2_Init();
  MX_ADC1_Init();
  MX_ADC2_Init();
  MX_ADC3_Init();
  MX_TIM14_Init();
  MX_TIM5_Init();

  /* USER CODE BEGIN 2 */

  //delete MX_LWIP_Init() in TOP!

	////////preparing massives
	for(mi=0;mi<15;mi++)
		{
		UTILITY_BASE[mi][19] = 0;	
		}
	for(mi=0;mi<11;mi++)
		{
		EP_BASE[mi][7] = 0;	
		}
	for(mi=0;mi<5;mi++)
		{
		EL_BASE[mi][16] = 0;
		}
	for(mi=0;mi<2;mi++)
		{
		DD_BASE[mi][3] = 0;
		}	
	for(mi=0;mi<4;mi++)
		{
		EU_BASE[mi][14] = 0;
		}	
	for(mi=0;mi<8;mi++)
		{
		EPD_BASE[mi][8] = 0;
		}		
		
	DEVICE_UID = *(unsigned long*)(0x1FF0F420);							//Read device ID
	
	#if defined(USART_DEBUG)
		USART1->CR1 |= USART_CR1_RXNEIE; //interrupt for a RX enable
	#endif	
	
	if(HAL_GPIO_ReadPin(KEY_PRESET_GPIO_Port, KEY_PRESET_Pin)==0 && HAL_GPIO_ReadPin(GPIOD, KEY_EFFECT_Pin)==0 &&							//Check service mode combination
		HAL_GPIO_ReadPin(GPIOB, KEY_SHIFT_Pin)==1 && HAL_GPIO_ReadPin(GPIOB, KEY_EDIT_Pin)==1 &&
		HAL_GPIO_ReadPin(GPIOF, KEY_MENU_Pin)==1 && HAL_GPIO_ReadPin(GPIOD, KEY_BACK_Pin)==1 &&
		HAL_GPIO_ReadPin(KEY_SYNC_OUT_GPIO_Port, KEY_SYNC_OUT_Pin)==1 && HAL_GPIO_ReadPin(GPIOF, KEY_ENC_Pin)==1)
		{
		SERVICE_MODE_ENABLE++;	
		}
	for(mi=0;mi<8;mi++)
		{	
		COLOR_SET(PIO_PAD_COLOR, mi);
		}
	HAL_SPI_Transmit_DMA(&hspi2, COLOR, 100);	
	HAL_Delay(5);	
	HAL_SPI_Transmit_DMA(&hspi2, COLOR, 100);	
	
	HAL_TIM_Base_Start_IT(&htim5);				//ENCODER
		
	TIM14->CCR1 = 0;		//PWM BLACKLIGHT
	HAL_TIM_PWM_Start(&htim14, TIM_CHANNEL_1);		//PWM BLACKLIGHT
	
	if(HAL_GPIO_ReadPin(KEY_PRESET_GPIO_Port, KEY_PRESET_Pin)==0 && HAL_GPIO_ReadPin(GPIOD, KEY_EFFECT_Pin)==0 &&							//Check service mode combination
		HAL_GPIO_ReadPin(GPIOB, KEY_SHIFT_Pin)==1 && HAL_GPIO_ReadPin(GPIOB, KEY_EDIT_Pin)==1 &&
		HAL_GPIO_ReadPin(GPIOF, KEY_MENU_Pin)==1 && HAL_GPIO_ReadPin(GPIOD, KEY_BACK_Pin)==1 &&
		HAL_GPIO_ReadPin(KEY_SYNC_OUT_GPIO_Port, KEY_SYNC_OUT_Pin)==1 && HAL_GPIO_ReadPin(GPIOF, KEY_ENC_Pin)==1)
		{
		SERVICE_MODE_ENABLE++;	
		}
	
	HAL_GPIO_WritePin(GPIOB, LED_ENC_Pin|LED_SHIFT_Pin, GPIO_PIN_SET);										//////////////////////////////
	HAL_GPIO_WritePin(GPIOA, LED_PRESET_Pin|LED_EFFECT_Pin, GPIO_PIN_SET);								//
	HAL_GPIO_WritePin(LED_SYNC_OUT_GPIO_Port, LED_SYNC_OUT_Pin, GPIO_PIN_SET);						//			turn on leds
	HAL_GPIO_WritePin(GPIOI, LED_EDIT_Pin, GPIO_PIN_SET);																	//
	HAL_GPIO_WritePin(LED_MENU_GPIO_Port, LED_MENU_Pin, GPIO_PIN_SET);										//////////////////////////////
	
	BSP_QSPI_Init();
  BSP_QSPI_MemoryMappedMode();
	WRITE_REG(QUADSPI->LPTR, 0xFFF);

	BSP_SD_Init();
		
	lcd_status = BSP_LCD_Init();
	BSP_LCD_LayerDefaultInit(0, LCD_FRAME_BUFFER);
	BSP_LCD_LayerDefaultInit(1, LCD_FRAME_BUFFER_2);
	
	BSP_LCD_SelectLayer(1);
	BSP_LCD_Clear(0x00000000);					//higher layer filling a transparent color
	BSP_LCD_SetTransparency(1, 255);	
	BSP_LCD_SelectLayer(0);
	BSP_LCD_SetTransparency(0, 255);
	BSP_LCD_Clear(LCD_COLOR_BLACK);
	BSP_LCD_SetBackColor(LCD_COLOR_BLACK);
	HAL_Delay(200);		//500	
	HAL_TIM_Base_Start_IT(&htim2);									//start timer
	HAL_Delay(200);		//500
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

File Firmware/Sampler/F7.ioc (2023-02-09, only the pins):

Mcu.UserName=STM32F746NGHx
PA0/WKUP.Signal=ADCx_IN0
PA1.Signal=ETH_REF_CLK
PA11.GPIO_Label=LED_EFFECT
PA11.Signal=GPIO_Output
PA13.GPIO_Label=SWDIO
PA13.Signal=SYS_JTMS-SWDIO
PA14.GPIO_Label=SWCLK
PA14.Signal=SYS_JTCK-SWCLK
PA15.GPIO_Label=LED_PRESET
PA15.Signal=GPIO_Output
PA2.Signal=ETH_MDIO
PA6.Signal=ADCx_IN6
PA7.Signal=ETH_CRS_DV
PA8.GPIO_Label=KEY_PRESET
PA8.Signal=GPIO_Input
PA9.GPIO_Label=VCP_TX [STM32F103CBT6_PA3]
PA9.Signal=USART1_TX
PB14.GPIO_Label=KEY_SHIFT
PB14.Signal=GPIO_Input
PB15.GPIO_Label=LED_SHIFT
PB15.Signal=GPIO_Output
PB2.Signal=QUADSPI_CLK
PB3.GPIO_Label=SWO
PB3.Signal=SYS_JTDO-SWO
PB4.GPIO_Label=PAD_3
PB4.Signal=GPIO_Input
PB6.GPIO_Label=QSPI_NCS [N25Q128A13EF840E_S]
PB6.Signal=QUADSPI_BK1_NCS
PB7.GPIO_Label=VCP_RX [STM32F103CBT6_PA2]
PB7.Signal=USART1_RX
PB8.GPIO_Label=LED_ENC
PB8.Signal=GPIO_Output
PB9.GPIO_Label=KEY_EDIT
PB9.Signal=GPIO_Input
PC1.Signal=ETH_MDC
PC10.GPIO_Label=SDMMC_D2
PC10.Signal=SDMMC1_D2
PC11.GPIO_Label=SDMMC_D3
PC11.Signal=SDMMC1_D3
PC12.GPIO_Label=SDMMC_CK
PC12.Signal=SDMMC1_CK
PC13.GPIO_Label=uSD_Detect
PC13.Signal=GPIO_Input
PC3.GPIO_Label=FMC_SDCKE0 [MT48LC4M32B2B5-6A_CKE]
PC3.Signal=FMC_SDCKE0
PC4.Signal=ETH_RXD0
PC5.Signal=ETH_RXD1
PC6.GPIO_Label=PAD_1
PC6.Signal=GPIO_Input
PC7.GPIO_Label=PAD_0
PC7.Signal=GPIO_Input
PC8.Signal=SDMMC1_D0
PC9.Signal=SDMMC1_D1
PD0.GPIO_Label=FMC_D2 [MT48LC4M32B2B5-6A_DQ2]
PD0.Signal=FMC_D2_DA2
PD1.GPIO_Label=FMC_D3 [MT48LC4M32B2B5-6A_DQ3]
PD1.Signal=FMC_D3_DA3
PD10.GPIO_Label=FMC_D15 [MT48LC4M32B2B5-6A_DQ15]
PD10.Signal=FMC_D15_DA15
PD11.GPIO_Label=QSPI_D0 [N25Q128A13EF840E_DQ0]
PD11.Signal=QUADSPI_BK1_IO0
PD12.GPIO_Label=QSPI_D1 [N25Q128A13EF840E_DQ1]
PD12.Signal=QUADSPI_BK1_IO1
PD13.GPIO_Label=QSPI_D3 [N25Q128A13EF840E_DQ3]
PD13.Signal=QUADSPI_BK1_IO3
PD14.GPIO_Label=FMC_D0 [MT48LC4M32B2B5-6A_DQ0]
PD14.Signal=FMC_D0_DA0
PD15.GPIO_Label=FMC_D1 [MT48LC4M32B2B5-6A_DQ1]
PD15.Signal=FMC_D1_DA1
PD2.GPIO_Label=SDMMC_D0
PD2.Signal=SDMMC1_CMD
PD3.Signal=SPI2_SCK
PD4.GPIO_Label=KEY_EFFECT
PD4.Signal=GPIO_Input
PD5.GPIO_Label=LED_SYNC_OUT
PD5.Signal=GPIO_Output
PD7.GPIO_Label=KEY_BACK
PD7.Signal=GPIO_Input
PD8.GPIO_Label=FMC_D13 [MT48LC4M32B2B5-6A_DQ13]
PD8.Signal=FMC_D13_DA13
PD9.GPIO_Label=FMC_D14 [MT48LC4M32B2B5-6A_DQ14]
PD9.Signal=FMC_D14_DA14
PE0.GPIO_Label=FMC_NBL0 [MT48LC4M32B2B5-6A_DQM0]
PE0.Signal=FMC_NBL0
PE1.GPIO_Label=FMC_NBL1 [MT48LC4M32B2B5-6A_DQM1]
PE1.Signal=FMC_NBL1
PE10.GPIO_Label=FMC_D7 [MT48LC4M32B2B5-6A_DQ7]
PE10.Signal=FMC_D7_DA7
PE11.GPIO_Label=FMC_D8 [MT48LC4M32B2B5-6A_DQ8]
PE11.Signal=FMC_D8_DA8
PE12.GPIO_Label=FMC_D9 [MT48LC4M32B2B5-6A_DQ9]
PE12.Signal=FMC_D9_DA9
PE13.GPIO_Label=FMC_D10 [MT48LC4M32B2B5-6A_DQ10]
PE13.Signal=FMC_D10_DA10
PE14.GPIO_Label=FMC_D11 [MT48LC4M32B2B5-6A_DQ11]
PE14.Signal=FMC_D11_DA11
PE15.GPIO_Label=FMC_D12 [MT48LC4M32B2B5-6A_DQ12]
PE15.Signal=FMC_D12_DA12
PE2.GPIO_Label=QSPI_D2 [N25Q128A13EF840E_DQ2]
PE2.Signal=QUADSPI_BK1_IO2
PE3.GPIO_Label=KEY_SYNC_OUT
PE3.Signal=GPIO_Input
PE4.GPIO_Label=LCD_B0 [RK043FN48H-CT672B_B0]
PE4.Signal=LTDC_B0
PE7.GPIO_Label=FMC_D4 [MT48LC4M32B2B5-6A_DQ4]
PE7.Signal=FMC_D4_DA4
PE8.GPIO_Label=FMC_D5 [MT48LC4M32B2B5-6A_DQ5]
PE8.Signal=FMC_D5_DA5
PE9.GPIO_Label=FMC_D6 [MT48LC4M32B2B5-6A_DQ6]
PE9.Signal=FMC_D6_DA6
PF0.GPIO_Label=FMC_A0 [MT48LC4M32B2B5-6A_A0]
PF0.Signal=FMC_A0
PF1.GPIO_Label=FMC_A1 [MT48LC4M32B2B5-6A_A1]
PF1.Signal=FMC_A1
PF10.Signal=ADC3_IN8
PF11.GPIO_Label=FMC_SDNRAS [MT48LC4M32B2B5-6A_RAS]
PF11.Signal=FMC_SDNRAS
PF12.GPIO_Label=FMC_A6 [MT48LC4M32B2B5-6A_A6]
PF12.Signal=FMC_A6
PF13.GPIO_Label=FMC_A7 [MT48LC4M32B2B5-6A_A7]
PF13.Signal=FMC_A7
PF14.GPIO_Label=FMC_A8 [MT48LC4M32B2B5-6A_A8]
PF14.Signal=FMC_A8
PF15.GPIO_Label=FMC_A9 [MT48LC4M32B2B5-6A_A9]
PF15.Signal=FMC_A9
PF2.GPIO_Label=FMC_A2 [MT48LC4M32B2B5-6A_A2]
PF2.Signal=FMC_A2
PF3.GPIO_Label=FMC_A3 [MT48LC4M32B2B5-6A_A3]
PF3.Signal=FMC_A3
PF4.GPIO_Label=FMC_A4 [MT48LC4M32B2B5-6A_A4]
PF4.Signal=FMC_A4
PF5.GPIO_Label=FMC_A5 [MT48LC4M32B2B5-6A_A5]
PF5.Signal=FMC_A5
PF6.GPIO_Label=KEY_ENC
PF6.Signal=GPIO_Input
PF7.GPIO_Label=KEY_MENU
PF7.Signal=GPIO_Input
PF8.GPIO_Label=LED_MENU
PF8.Signal=GPIO_Output
PF9.Signal=S_TIM14_CH1
PG0.GPIO_Label=FMC_A10 [MT48LC4M32B2B5-6A_A10]
PG0.Signal=FMC_A10
PG1.GPIO_Label=FMC_A11 [MT48LC4M32B2B5-6A_A11]
PG1.Signal=FMC_A11
PG10.GPIO_Label=SAI2_SDB [WM8994ECS/R_ADCDAT1]
PG10.Signal=SAI2_SD_B
PG11.Signal=ETH_TX_EN
PG12.GPIO_Label=LCD_B4 [RK043FN48H-CT672B_B4]
PG12.Signal=LTDC_B4
PG13.Signal=ETH_TXD0
PG14.Signal=ETH_TXD1
PG15.GPIO_Label=FMC_SDNCAS [MT48LC4M32B2B5-6A_CAS]
PG15.Signal=FMC_SDNCAS
PG2.GPIO_Label=RMII_RXER
PG2.Signal=GPIO_Input
PG3.GPIO_Label=EXT_RST
PG3.Signal=GPIO_Output
PG4.GPIO_Label=FMC_BA0 [MT48LC4M32B2B5-6A_BA0]
PG4.Signal=FMC_A14_BA0
PG5.GPIO_Label=FMC_BA1 [MT48LC4M32B2B5-6A_BA1]
PG5.Signal=FMC_A15_BA1
PG6.GPIO_Label=PAD_2
PG6.Signal=GPIO_Input
PG7.GPIO_Label=PAD_4
PG7.Signal=GPIO_Input
PG8.GPIO_Label=FMC_SDCLK [MT48LC4M32B2B5-6A_CLK]
PG8.Signal=FMC_SDCLK
PH0/OSC_IN.GPIO_Label=OSC_25M [NZ2520SB-25.00M_OUT]
PH0/OSC_IN.Signal=RCC_OSC_IN
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

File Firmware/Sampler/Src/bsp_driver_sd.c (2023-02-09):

/**
 ******************************************************************************
  * @file    bsp_driver_sd.c for F7 (based on stm32756g_eval_sd.c)
  * @brief   This file includes a generic uSD card driver.
  ******************************************************************************
  * This notice applies to any and all portions of this file
  * that are not between comment pairs USER CODE BEGIN and
  * USER CODE END. Other portions of this file, whether 
  * inserted by the user or by software development tools
  * are owned by their respective copyright owners.
  *
  * Copyright (c) 2021 STMicroelectronics International N.V. 
  * All rights reserved.
  *
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
  ******************************************************************************
  */

#define BUS_4BITS 1

#ifdef OLD_API
/* kept to avoid issue when migrating old projects. */
/* USER CODE BEGIN 0 */

/* Includes ------------------------------------------------------------------*/
#include "bsp_driver_sd.h"

/* Extern variables ---------------------------------------------------------*/ 
  
extern SD_HandleTypeDef _HSD;
extern HAL_SD_CardInfoTypedef _SD_CARD_INFO; 

/**
  * @brief  Initializes the SD card device.
  * @retval SD status
  */
uint8_t BSP_SD_Init(void)
{
  uint8_t sd_state = MSD_OK;
  /* Check if the SD card is plugged in the slot */
  if (BSP_SD_IsDetected() != SD_PRESENT)
  {
    return MSD_ERROR_SD_NOT_PRESENT;
  }
  /* HAL SD initialization */
  sd_state = HAL_SD_Init(&_HSD, &_SD_CARD_INFO);
#ifdef BUS_4BITS
  /* Configure SD Bus width */
  if (sd_state == MSD_OK)
  {
    /* Enable wide operation */
    if (HAL_SD_WideBusOperation_Config(&_HSD, SDMMC_BUS_WIDE_4B) != SD_OK)
    {
      sd_state = MSD_ERROR;
    }
    else
    {
      sd_state = MSD_OK;
    }
  }
#endif
  return sd_state;
}

/**
  * @brief  Configures Interrupt mode for SD detection pin.
  * @retval Returns 0 in success otherwise 1. 
  */
uint8_t BSP_SD_ITConfig(void)
{  
  /* TBI: add user code here depending on the hardware configuration used */
  
  return (uint8_t)0;
}

/**
  * @brief  Reads block(s) from a specified address in an SD card, in polling mode. 
  * @param  pData: Pointer to the buffer that will contain the data to transmit
  * @param  ReadAddr: Address from where data is to be read  
  * @param  BlockSize: SD card data block size, that should be 512
  * @param  NumOfBlocks: Number of SD blocks to read 
  * @retval SD status
  */
uint8_t BSP_SD_ReadBlocks(uint32_t *pData, uint64_t ReadAddr, uint32_t BlockSize, uint32_t NumOfBlocks)
{
  uint8_t sd_state;
  if(HAL_SD_ReadBlocks(&_HSD, pData, ReadAddr, BlockSize, NumOfBlocks) != SD_OK)  
  {
    sd_state = MSD_ERROR;
  }
  else
  {
    sd_state = MSD_OK;
  }
  return sd_state;  
}

/**
  * @brief  Writes block(s) to a specified address in an SD card, in polling mode. 
  * @param  pData: Pointer to the buffer that will contain the data to transmit
  * @param  WriteAddr: Address from where data is to be written  
  * @param  BlockSize: SD card data block size, that should be 512
  * @param  NumOfBlocks: Number of SD blocks to write
  * @retval SD status
  */
uint8_t BSP_SD_WriteBlocks(uint32_t *pData, uint64_t WriteAddr, uint32_t BlockSize, uint32_t NumOfBlocks)
{
  uint8_t sd_state;
  if(HAL_SD_WriteBlocks(&_HSD, pData, WriteAddr, BlockSize, NumOfBlocks) != SD_OK)  
  {
    sd_state = MSD_ERROR;
  }
  else
  {
    sd_state = MSD_OK;
  }
  return sd_state;  
}

/**
  * @brief  Reads block(s) from a specified address in an SD card, in DMA mode.
  * @param  pData: Pointer to the buffer that will contain the data to transmit
  * @param  ReadAddr: Address from where data is to be read  
  * @param  BlockSize: SD card data block size, that should be 512
  * @param  NumOfBlocks: Number of SD blocks to read 
  * @retval SD status
  */
uint8_t BSP_SD_ReadBlocks_DMA(uint32_t *pData, uint64_t ReadAddr, uint32_t BlockSize, uint32_t NumOfBlocks)
{
  uint8_t sd_state = MSD_OK;
  
  /* Read block(s) in DMA transfer mode */
  if(HAL_SD_ReadBlocks_DMA(&_HSD, pData, ReadAddr, BlockSize, NumOfBlocks) != SD_OK)  
  {
    sd_state = MSD_ERROR;
  }
  
  /* Wait until transfer is complete */
  if(sd_state == MSD_OK)
  {
    if(HAL_SD_CheckReadOperation(&_HSD, (uint32_t)SD_DATATIMEOUT) != SD_OK)  
    {
      sd_state = MSD_ERROR;
    }
    else
    {
      sd_state = MSD_OK;
    }
  }
  
  return sd_state; 
}

/**
  * @brief  Writes block(s) to a specified address in an SD card, in DMA mode.  
  * @param  pData: Pointer to the buffer that will contain the data to transmit
  * @param  WriteAddr: Address from where data is to be written  
  * @param  BlockSize: SD card data block size, that should be 512
  * @param  NumOfBlocks: Number of SD blocks to write 
  * @retval SD status
  */
uint8_t BSP_SD_WriteBlocks_DMA(uint32_t *pData, uint64_t WriteAddr, uint32_t BlockSize, uint32_t NumOfBlocks)
{
  uint8_t sd_state = MSD_OK;
  
  /* Write block(s) in DMA transfer mode */
  if(HAL_SD_WriteBlocks_DMA(&_HSD, pData, WriteAddr, BlockSize, NumOfBlocks) != SD_OK)  
  {
    sd_state = MSD_ERROR;
  }
  
  /* Wait until transfer is complete */
  if(sd_state == MSD_OK)
  {
    if(HAL_SD_CheckWriteOperation(&_HSD, (uint32_t)SD_DATATIMEOUT) != SD_OK)  
    {
      sd_state = MSD_ERROR;
    }
    else
    {
      sd_state = MSD_OK;
    }
  }
  
  return sd_state; 
}

/**
  * @brief  Erases the specified memory area of the given SD card. 
  * @param  StartAddr: Start byte address
  * @param  EndAddr: End byte address
  * @retval SD status
  */
uint8_t BSP_SD_Erase(uint64_t StartAddr, uint64_t EndAddr)
{
  uint8_t sd_state;
  if(HAL_SD_Erase(&_HSD, StartAddr, EndAddr) != SD_OK)  
  {
    sd_state = MSD_ERROR;
  }
  else
  {
    sd_state = MSD_OK;
  }
  return sd_state; 
}

/**
  * @brief  Gets the current SD card data status.
  * @retval Data transfer state.
  *          This value can be one of the following values:
  *            @arg  SD_TRANSFER_OK: No data transfer is acting
  *            @arg  SD_TRANSFER_BUSY: Data transfer is acting
  *            @arg  SD_TRANSFER_ERROR: Data transfer error 
  */
HAL_SD_TransferStateTypedef BSP_SD_GetStatus(void)
{
  return(HAL_SD_GetStatus(&_HSD));
}

/**
  * @brief  Get SD information about specific SD card.
  * @param  CardInfo: Pointer to HAL_SD_CardInfoTypedef structure
  */
void BSP_SD_GetCardInfo(HAL_SD_CardInfoTypedef* CardInfo)
{
  /* Get SD card Information */
  HAL_SD_Get_CardInfo(&_HSD, CardInfo);
}
/* USER CODE END 0 */
#else
/* USER CODE BEGIN FirstSection */
/* can be used to modify / undefine following code or add new definitions */
/* USER CODE END FirstSection */
/* Includes ------------------------------------------------------------------*/
#include "bsp_driver_sd.h"

/* Extern variables ---------------------------------------------------------*/ 
  
extern SD_HandleTypeDef _HSD;
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

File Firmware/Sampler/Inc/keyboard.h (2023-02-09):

/////////////////////////////////////////////////////////////////////////////////////////////////
// 	KEYBOARD GUI part
//	product: DJS-500 sampler
//
//
//
//
//	Author: Anatska Andrei
//
/////////////////////////////////////////////////////////////////////////////////////////////////

#include "stdint.h"
void int_KBRD_(uint8_t updwn);					//internal function for keyboard
void int_TYPING(void);									//internal function for keyboard
void int_RET_PRST_NAME(void);						//internal function for keyboard
void int_blinking_cursor(void);					//internal function for keyboard

/////////////////////////////////////////////////	
//
//internal function for keyboard
//		
void int_KBRD_(uint8_t updwn)
	{
	BSP_LCD_SelectLayer(0);				
	BSP_LCD_SetTextColor(LCD_COLOR_BLACK);	
	if(KBRD_Position==36 || KBRD_Position==73)
		{
		BSP_LCD_FillRect(1+13*(KBRD_Position%37), 217+26*(KBRD_Position/37), 10, 19);	
		BSP_LCD_DrawLine(13*(KBRD_Position%37),  218+26*(KBRD_Position/37), 13*(KBRD_Position%37), 234+26*(KBRD_Position/37));	
		BSP_LCD_DrawLine(11+13*(KBRD_Position%37),  218+26*(KBRD_Position/37), 11+13*(KBRD_Position%37), 234+26*(KBRD_Position/37));
		}
	else		
		{
		BSP_LCD_FillRect(1+13*(KBRD_Position%37), 217+26*(KBRD_Position/37), 11, 19);	
		BSP_LCD_DrawLine(13*(KBRD_Position%37),  218+26*(KBRD_Position/37), 13*(KBRD_Position%37), 234+26*(KBRD_Position/37));	
		BSP_LCD_DrawLine(12+13*(KBRD_Position%37),  218+26*(KBRD_Position/37), 12+13*(KBRD_Position%37), 234+26*(KBRD_Position/37));	
		}
	BSP_LCD_SelectLayer(1);		
	Buf[0] = lttrs[KBRD_Position/37][KBRD_Position%37];
	Buf[1] = 0;	
	if((KBRD_Position%37)<5 || (KBRD_Position%37)>30)
		{
		if(KBRD_Position==73)
			{
			BSP_LCD_SetTextColor(KBRD_RED_COLOR);		
			}						
		else
			{						
			BSP_LCD_SetTextColor(PATH_COLOR);	
			}
		}	
	else
		{
		BSP_LCD_SetTextColor(LCD_COLOR_WHITE);	
		}	
	BSP_LCD_DisplayStringAt(letter_offs[KBRD_Position/37][KBRD_Position%37], 219+26*(KBRD_Position/37), Buf, TRANSPARENT_MODE);			
	
	if(updwn==KBRD_UP)
		{
		if(KBRD_Position<73)
			{
			KBRD_Position++;
			}
		else
			{
			return;	
			}			
		}
	else if(updwn==KBRD_DOWN)
		{
		if(KBRD_Position>0)
			{
			KBRD_Position--;
			}
		else
			{
			return;	
			}			
		}	
	else if(updwn==KBRD_SH_UP)
		{
		if(KBRD_Position<37)
			{
			KBRD_Position+=37;
			}
		else
			{
			return;	
			}		
		}		
	else if(updwn==KBRD_SH_DOWN)
		{
		if(KBRD_Position>36)
			{
			KBRD_Position-=37;
			}
		else
			{
			return;	
			}			
		}		
	BSP_LCD_SelectLayer(0);				
	if((KBRD_Position%37)<5 || (KBRD_Position%37)>30)
		{
		if(KBRD_Position==73)
			{
			BSP_LCD_SetTextColor(KBRD_RED_COLOR);		
			}						
		else
			{						
			BSP_LCD_SetTextColor(PATH_COLOR);	
			}
		}	
	else
		{
		BSP_LCD_SetTextColor(LCD_COLOR_WHITE);	
		}	
	if(KBRD_Position==36 || KBRD_Position==73)
		{
		BSP_LCD_FillRect(1+13*(KBRD_Position%37), 217+26*(KBRD_Position/37), 10, 19);	
		BSP_LCD_DrawLine(13*(KBRD_Position%37),  218+26*(KBRD_Position/37), 13*(KBRD_Position%37), 234+26*(KBRD_Position/37));	
		BSP_LCD_DrawLine(11+13*(KBRD_Position%37),  218+26*(KBRD_Position/37), 11+13*(KBRD_Position%37), 234+26*(KBRD_Position/37));
		}
	else		
		{
		BSP_LCD_FillRect(1+13*(KBRD_Position%37), 217+26*(KBRD_Position/37), 11, 19);	
		BSP_LCD_DrawLine(13*(KBRD_Position%37),  218+26*(KBRD_Position/37), 13*(KBRD_Position%37), 234+26*(KBRD_Position/37));	
		BSP_LCD_DrawLine(12+13*(KBRD_Position%37),  218+26*(KBRD_Position/37), 12+13*(KBRD_Position%37), 234+26*(KBRD_Position/37));	
		}
	BSP_LCD_SelectLayer(1);		
	Buf[0] = lttrs[KBRD_Position/37][KBRD_Position%37];
	Buf[1] = 0;	
	BSP_LCD_SetTextColor(LCD_COLOR_BLACK);
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

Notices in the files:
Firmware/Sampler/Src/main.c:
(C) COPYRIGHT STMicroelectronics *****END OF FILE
